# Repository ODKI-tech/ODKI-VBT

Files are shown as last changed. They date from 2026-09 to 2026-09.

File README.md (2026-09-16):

# ODKI VBT

**[odki.tech](https://odki.tech)** — project site, pre-orders, and the companion app.

ODKI VBT is a source-available **Velocity-Based Training (VBT)** sensor — a small wireless device that clips onto a barbell (or is otherwise attached to the load being lifted) and measures bar velocity, displacement, and rep count in real time, streaming the results to a companion app over Bluetooth Low Energy. Build your own from the files here for personal or research use, or buy a ready-made, ODKI-branded unit at [odki.tech](https://odki.tech) — see the license note below for exactly what "source-available" means here.

Velocity-based training uses how *fast* a lift moves — not just the weight on the bar — to gauge effort, fatigue, and training intensity in real time, which is the whole reason this project exists: an accessible, understandable, hackable device to do that.

Both the hardware and the firmware are source-available: anyone can read exactly how it works, build one for themselves, modify it, and share their own non-commercial improvements. Selling an assembled unit — under the ODKI name or otherwise, built from these files or a modified version of them — is reserved to ODKI; that's the one thing this isn't open to. See [LICENSE-FIRMWARE](LICENSE-FIRMWARE) and [LICENSE-HARDWARE](LICENSE-HARDWARE) for the exact terms of each, and [CONTRIBUTING.md](CONTRIBUTING.md) for how contributing to the official repository works.

## How it works, briefly

The sensor fuses its onboard accelerometer and gyroscope into a stable orientation estimate, uses that to isolate real acceleration from gravity, integrates it into velocity along the vertical axis, and detects individual reps from that velocity signal — continuously correcting for drift using brief natural pauses in motion, without requiring the athlete to explicitly mark the start/end of each rep. Every rep's peak/mean velocity, acceleration, displacement, and a data-quality score are reported live. The full algorithm is documented in detail in [`Firmware/DOCUMENTATION.md`](Firmware/DOCUMENTATION.md).

## Repository layout

- **[Hardware/](Hardware/)** — bill of materials, CAD/mechanical design files, and assembly instructions for building a unit.
- **[Firmware/](Firmware/)** — the Arduino C++ firmware source (`VBT_Quaternions/`), [`DOCUMENTATION.md`](Firmware/DOCUMENTATION.md) (a chapter-by-chapter reference covering what every source file does and the rep-detection algorithm in detail), [`BLE_PROTOCOL.md`](Firmware/BLE_PROTOCOL.md) (the byte-exact Bluetooth protocol spec — everything a third-party app needs to talk to the sensor), and two Python tools: `tools/vbt_log_viewer.py`, for replaying and visualizing a raw debug-log capture from the device, and `tools/vbt_live_monitor.py`, a desktop GUI that shows that same data live over a USB-serial connection and can drive calibration/start/stop directly, no phone app needed.
- **[Apps/](Apps/)** — download links and usage instructions for the companion app (Android, iOS, Windows).
- **[LICENSE-FIRMWARE](LICENSE-FIRMWARE)** (GPL-3.0 + Commons Clause) / **[LICENSE-HARDWARE](LICENSE-HARDWARE)** (CC BY-NC-SA 4.0) — non-commercial use, modification, and redistribution allowed; selling a unit built from these files is reserved to ODKI. The BLE protocol specification itself ([`Firmware/BLE_PROTOCOL.md`](Firmware/BLE_PROTOCOL.md)) is separately released under CC0 (public domain), so third-party apps can be built against it without restriction.

## Getting started

1. **Build the hardware.** The [bill of materials](Hardware/BOM/), [CAD/mechanical design](Hardware/CAD/), and [step-by-step assembly instructions](Hardware/Instructions/) are all published — start there.
2. **Flash the firmware.** Open `Firmware/VBT_Quaternions/VBT_Quaternions.ino` in the Arduino IDE with the `Seeeduino:nrf52` board package installed (board: `xiaonRF52840Sense`) and the `Seeed Arduino LSM6DS3` library, then upload. See [`Firmware/DOCUMENTATION.md`](Firmware/DOCUMENTATION.md) for what each file does and how the algorithm works.
3. **Install the app.** See [Apps/](Apps/) for your platform — currently pending first public release.
4. **Calibrate and lift.** Power on, connect over Bluetooth, calibrate the sensor while it's still, then start tracking a set.

## Contributing

Both the hardware and firmware are meant to be read and modified. `Firmware/DOCUMENTATION.md` is written specifically to get a new contributor from "never seen this codebase" to "can confidently modify the rep-detection algorithm" — start there. See [`CONTRIBUTING.md`](CONTRIBUTING.md) for how to report a bug, propose a change, and the code style expected in a pull request.

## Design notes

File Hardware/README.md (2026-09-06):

# Hardware

This folder holds everything needed to build the ODKI VBT sensor's physical hardware. The current reference design is built around a **Seeed XIAO nRF52840 Sense** module (which already integrates the nRF52840 MCU, an LSM6DS3TR-C accelerometer/gyroscope, BLE radio, and USB-C/battery charging), plus a LiPo battery and a physical power switch — see `Firmware/DOCUMENTATION.md` for how the firmware expects that switch to be wired (`WAKE_PIN`, `Config.h`).

- **[BOM/](BOM/)** — bill of materials: every part needed to build one unit, with quantities and key specs (no sourcing links — where to buy each part is up to you, see the note in [BOM/README.md](BOM/README.md)).
- **[CAD/](CAD/)** — the two-body enclosure design (source + print-ready files) and, if a custom PCB is ever designed instead of using the XIAO module directly, its schematic/layout sources.
- **[Instructions/](Instructions/)** — step-by-step assembly instructions, from raw parts to a working, closed unit ready to flash.

See [LICENSE-HARDWARE](../LICENSE-HARDWARE) at the project root for the license status of everything in this folder.

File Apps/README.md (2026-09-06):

# Apps

The ODKI VBT companion app connects to the sensor over Bluetooth Low Energy to calibrate it, start/stop tracking, view live velocity/rep data, and install firmware updates over the air.

**License note:** unlike the firmware and hardware design files in this repository, the app itself is closed-source and is not covered by [`LICENSE-FIRMWARE`](../LICENSE-FIRMWARE) or [`LICENSE-HARDWARE`](../LICENSE-HARDWARE) — only builds/installers are distributed here, no app source. Some of its features (training-data management, AI-based analysis) are paid; this has no effect on using the sensor itself, which works over the fully open [BLE protocol](../Firmware/BLE_PROTOCOL.md) regardless of which app — this one or a third-party alternative — you use with it.

Download and setup instructions for each platform:

- **[Android/](Android/)** — published.
- **[iOS/](iOS/)** — not yet published.
- **[Windows/](Windows/)** — not yet published.

See each platform's README for current status and, once published, the download link.

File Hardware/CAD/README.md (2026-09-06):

# CAD

Mechanical design source files for the ODKI VBT enclosure.

## Design

Two printed bodies, bonded together permanently with cyanoacrylate (superglue) rather than screwed or snap-fit — there is no intended way to reopen a unit non-destructively once assembled (replacing the battery means breaking the bond and reprinting/regluing).

- **`case-top`** — the main shell, holding the Seeed XIAO nRF52840 Sense. An internal rail guides the board into position as it slides in, until its USB-C connector lines up with a cutout in one of the two short end walls. The **opposite short end** has its own dedicated recess for the power switch. The top face also has a small separate oval window positioned over the onboard RGB status LED, so its color is visible from outside with the case fully closed.
- **`case-bottom`** — the shallower base, holding the LiPo battery and the 3 neodymium magnets (see [`Hardware/BOM`](../BOM/)) in their own blind pockets in the floor of the same compartment, used for the barbell-mount attachment. The magnets go in before the battery is placed, since the battery sits on top of them once the body is populated. A small integrated post does double duty: it keeps the battery from shifting inside the compartment, and — once the two halves are joined — it backs up the XIAO board from behind, so it can't be pushed back out of `case-top`'s rail if the USB-C cable is inserted with some force.

Because the USB-C port stays reachable through `case-top`'s cutout even once the unit is glued shut, a finished unit can still be charged over USB normally, day to day, without ever opening the case — that's the cutout's main job. Re-flashing over USB is also possible through the same cutout, but is only ever a fallback: normal firmware updates go over BLE DFU instead (see `Firmware/DOCUMENTATION.md`).

| `case-bottom`, interior | `case-top`, exterior | `case-top`, interior |
|---|---|---|
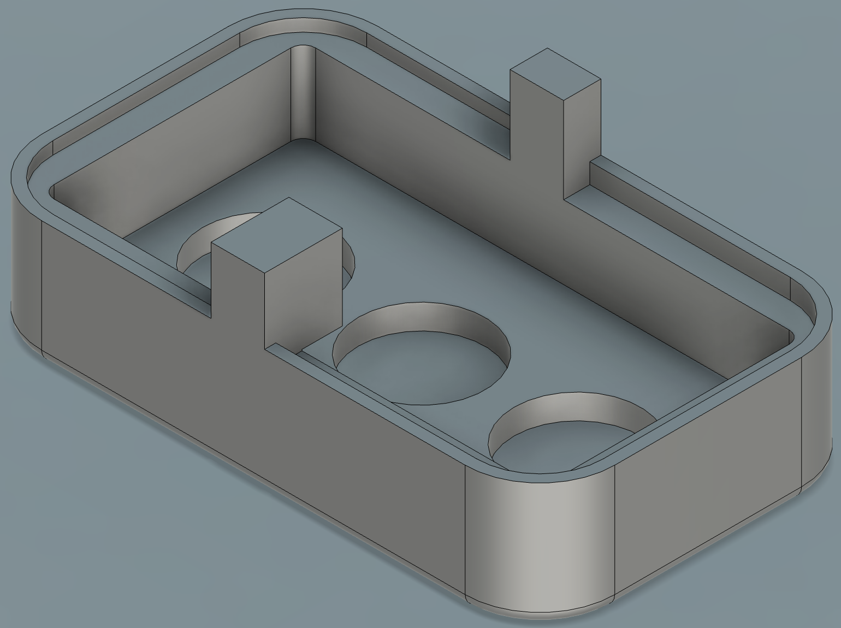
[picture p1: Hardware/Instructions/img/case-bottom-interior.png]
case-bottom interior, magnet pockets
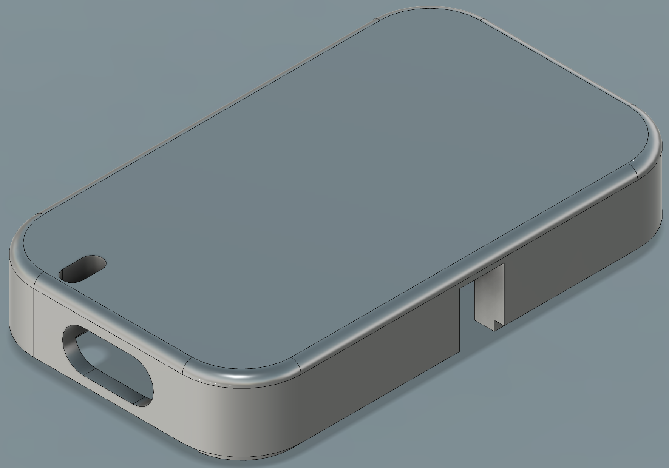
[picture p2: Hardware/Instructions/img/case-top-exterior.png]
case-top exterior, USB-C cutout and switch recess
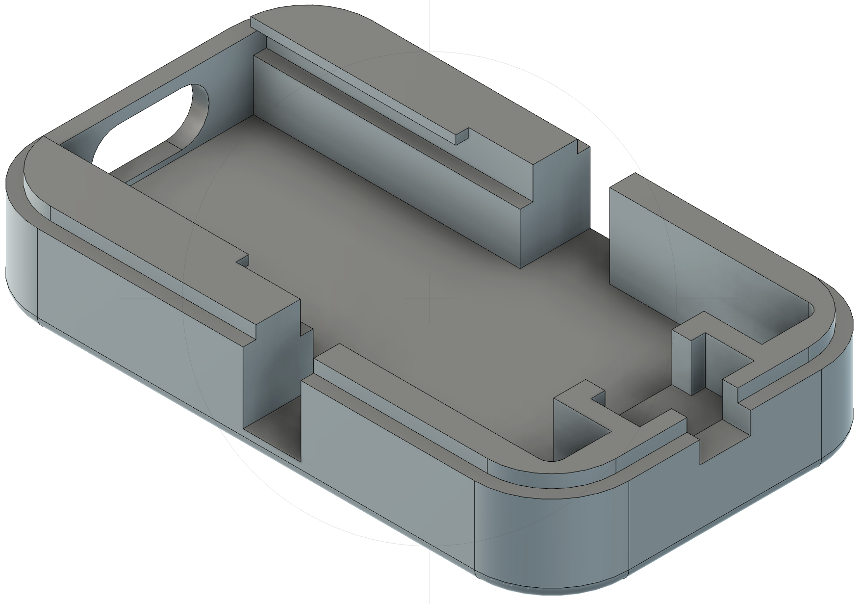
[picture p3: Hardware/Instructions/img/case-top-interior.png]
case-top interior, board rail and USB-C cutout
|  |  |  |

(Designed in Fusion 360. If a custom PCB is ever designed instead of using the XIAO module directly, its schematic/layout sources (e.g. KiCad) and exported gerbers would also go in this folder.)

## Print settings

Reference settings used for both bodies, printed in **PLA**:

| Setting | Value |
|---|---|
| Layer height | 0.2mm |
| Infill | 95% |
| Supports | Not needed for `case-top`; required for `case-bottom` |

## Files

| File | Format | Purpose |
|---|---|---|
| [`case-top.step`](case-top.step) | STEP | Editable source, opens in FreeCAD or any other CAD tool |
| [`case-top.stl`](case-top.stl) | STL | Ready-to-print mesh, for a slicer (Cura, PrusaSlicer, etc.) |
| [`case-bottom.step`](case-bottom.step) | STEP | Same as above, bottom body |
| [`case-bottom.stl`](case-bottom.stl) | STL | Same as above, bottom body |
| [`case-top.f3d`](case-top.f3d) / [`case-bottom.f3d`](case-bottom.f3d) | Fusion 360 archive | Optional — only useful to someone who also has Fusion and wants the full parametric history (sketches, feature timeline), which STEP does not preserve |

See [`Hardware/Instructions`](../Instructions/) for how these bodies fit together with the electronics into a finished unit.

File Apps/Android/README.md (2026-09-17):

# Android

**Status: published.** [Download the latest APK](https://github.com/ODKI-tech/ODKI-VBT/raw/main/Apps/Android/app-release/odki-vbt-latest.apk).

## Download & install

Distributed as a downloadable APK directly from [`app-release/`](app-release/) in this repository (sideload — no Google Play listing planned initially). Unlike the firmware (which self-checks for updates in-app), there's no auto-update mechanism for the app itself yet — check back here for a newer `.apk`.

1. Download [`odki-vbt-latest.apk`](https://github.com/ODKI-tech/ODKI-VBT/raw/main/Apps/Android/app-release/odki-vbt-latest.apk) — always the current release, regardless of version (see the note for maintainers below). Use the `github.com/.../raw/...` link specifically, not a plain `raw.githubusercontent.com` one — the APK is stored with Git LFS (see `.gitattributes`), and only the former correctly redirects to the actual binary; the latter serves the LFS pointer text instead (133 bytes, not the app).
2. Android will likely warn that installing from outside the Play Store is blocked — go to **Settings → Apps → Special access → Install unknown apps**, select the app you downloaded with (e.g. your browser or file manager), and allow it. The exact wording/path varies a bit by Android version and manufacturer.
3. Open the downloaded `.apk` and confirm the install.
4. To update later, just download and install the newer `.apk` the same way — it installs over the existing app as long as it's signed with the same key, no need to uninstall first.

**Note for maintainers, cutting a new release:** build the APK (`flutter build apk --release` in the app repo), overwrite `app-release/odki-vbt-latest.apk` with it, delete any other `.apk` left over in this folder, and bump `version` in the app repo's `pubspec.yaml` — same "keep only the latest, git history is the archive" convention as [`Firmware/firmware-release/`](../../Firmware/firmware-release/README.md). Keeping the filename itself stable (not versioned) is deliberate: it's what lets the link above, and everywhere else in this repo's docs, never need updating.

## Usage

1. Power on the sensor (see Hardware/Instructions).
2. Open the app, grant Bluetooth and location permissions when prompted (required by Android for BLE scanning).
3. Connect to the sensor from the device list.
4. Calibrate (hold the sensor/bar still and tap Calibrate).
5. Start a set to see live velocity and rep data; each completed rep appears automatically.
6. Firmware updates, when available, are offered in-app.

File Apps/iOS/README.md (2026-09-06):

# iOS

**Status: not yet published.** Link coming soon.

Planned distribution: TestFlight (Apple's beta-testing platform) for early testers, ahead of a possible App Store release. Once a TestFlight build is available, this page will list the invite link and installation steps (installing the free TestFlight app from the App Store, then redeeming the invite).

## Usage

1. Power on the sensor (see Hardware/Instructions).
2. Open the app, grant Bluetooth permission when prompted.
3. Connect to the sensor from the device list.
4. Calibrate (hold the sensor/bar still and tap Calibrate).
5. Start a set to see live velocity and rep data; each completed rep appears automatically.
6. Firmware updates, when available, are offered in-app.

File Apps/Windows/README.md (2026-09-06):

# Windows

**Status: not yet published.** Link coming soon.

Planned distribution: a downloadable installer/zip attached to this repository's GitHub Releases. Once published, this page will list the download link and setup steps. Note Windows PCs don't have built-in BLE peripheral tooling the way phones do — a Bluetooth LE-capable adapter (most modern laptops have one built in) is required.

## Usage

1. Power on the sensor (see Hardware/Instructions).
2. Open the app; pair/connect to the sensor from the device list.
3. Calibrate (hold the sensor/bar still and click Calibrate).
4. Start a set to see live velocity and rep data; each completed rep appears automatically.
5. Firmware updates, when available, are offered in-app.

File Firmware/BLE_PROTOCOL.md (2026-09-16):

# ODKI VBT — BLE Protocol Reference

**License note:** unlike the rest of this repository, *this document* is released under **CC0 1.0** (public domain dedication, see the [License](#license) section at the end) — deliberately, so any third-party app or integration can implement a client against it with zero legal uncertainty, commercial or not.

This is the byte-exact specification of the sensor's Bluetooth Low Energy interface: every characteristic UUID, every packet's layout down to the byte offset, and every scale factor needed to turn a raw value back into a physical one. It's written so a **third-party client** — a script, a different mobile app, a home-automation integration, anything — can talk to the device without needing to read the firmware source at all.

For *why* the protocol is shaped this way (why `Stream` is always raw, why `CorrectedCurve` exists and arrives late, why `RepSummary` can repeat), see the [BleServer chapter](DOCUMENTATION.md#bleserver) of the main firmware documentation — this document only covers *what's on the wire*, not the reasoning behind it. Reference implementation: `BleServer.h`/`.cpp` in this repository.

## Conventions

- **Byte order:** little-endian throughout — the nRF52840's native order, and standard for BLE.
- **No padding:** every packet struct in the firmware is declared `#pragma pack(push, 1)`, so byte offsets below are a plain cumulative sum of field sizes, with nothing inserted between fields.
- **Fixed-point physical values:** most quantities travel as a scaled integer, not a float: `physical_value = raw_value / scale`. This is called out per field below. A `scale` of `1` means the integer *is* the value directly (no conversion needed) — this is used for millisecond durations and millimetre-per-second velocities, so the wire value is already in a convenient integer unit.
- **Security:** every custom characteristic is open — `SECMODE_OPEN`, no pairing or bonding required for either read/notify or write access. Any BLE-capable device within range can connect, read live data, and issue `Command`/`Config` writes (including stopping tracking or changing algorithm parameters) without authentication. Keep this in mind if deploying in a setting where that matters.

## Advertising & connecting

| | |
|---|---|
| Device name | `VBT-Sensor` |
| Advertised service | the custom service UUID below |
| Role | Peripheral only (never Central) — exactly one simultaneous connection |
| Pairing | None required |

**MTU is mandatory to negotiate.** The default BLE MTU (23 bytes, 20 usable) is smaller than every custom packet except `Command`, `SystemStatus`, and `Battery`. Request the largest MTU the stack allows (the firmware itself requests up to 247 bytes on connect) before expecting `Stream`, `RepSummary`, `CorrectedCurve`, or `Config` to work — a client that skips this will simply never receive a successful notify for those characteristics.

## All UUIDs at a glance

| Name | UUID | Properties | Size |
|---|---|---|---|
| ODKI VBT Service | `6c7325bb-1784-4d77-8b99-89ce838ac2ab` | — | — |
| Stream | `6c7325bb-1784-4d77-8b99-89ce838ac2ac` | Notify | 37 B |
| RepSummary | `6c7325bb-1784-4d77-8b99-89ce838ac2ad` | Notify | 17 B |
| CorrectedCurve | `6c7325bb-1784-4d77-8b99-89ce838ac2ae` | Notify | 53 B |
| SystemStatus | `6c7325bb-1784-4d77-8b99-89ce838ac2af` | Read, Notify | 2 B |
| Command | `6c7325bb-1784-4d77-8b99-89ce838ac2b0` | Write | 1 B |
| Config | `6c7325bb-1784-4d77-8b99-89ce838ac2b2` | Read, Write | 38 B |
| Battery Service | `0x180F` (standard) | — | — |
| Battery Level | `0x2A19` (standard) | Read, Notify | 1 B |
| Device Information Service | `0x180A` (standard) | — | — |
| Firmware Revision String | `0x2A26` (standard) | Read | variable (UTF-8) |
| Buttonless DFU Service | `00001530-1212-efde-1523-785feabcd123` | — | — |
| DFU Control | `00001531-1212-efde-1523-785feabcd123` | Write, Notify | 1 B (command) |

(The custom UUIDs all share the base `6c7325bb-1784-4d77-8b99-89ce838ac2ab`, incrementing only the last byte — `0xb1` is intentionally absent from the sequence, freed when the original custom Battery and Firmware-Version characteristics were replaced by the two standard SIG services above.)

---

## Stream — `…c2ac`, Notify, 37 bytes

Live telemetry, sent only while tracking is active, decimated to 20Hz (`Config::STREAM_DECIMATION_FACTOR`). Automatically disabled while a raw serial debug capture is running.

| Offset | Size | Field | Type | Scale | Unit |
|---|---|---|---|---|---|
| 0 | 4 | `timestampMs` | uint32 | 1 | ms |
| 4 | 2 | `linAccX` | int16 | ÷100 | m/s² (sensor frame) |
| 6 | 2 | `linAccY` | int16 | ÷100 | m/s² |
| 8 | 2 | `linAccZ` | int16 | ÷100 | m/s² |
| 10 | 2 | `worldAccX` | int16 | ÷100 | m/s² (world frame) |
| 12 | 2 | `worldAccY` | int16 | ÷100 | m/s² |
| 14 | 2 | `worldAccZ` | int16 | ÷100 | m/s² |
| 16 | 2 | `worldVelX` | int16 | ÷1000 | m/s (debug/streaming only) |
| 18 | 2 | `worldVelY` | int16 | ÷1000 | m/s |
| 20 | 2 | `refVelZ` | int16 | ÷1000 | m/s — **raw**, live-re-anchored vertical velocity; never the retroactively-corrected value (see `CorrectedCurve` below) |
| 22 | 2 | `worldPosX` | int16 | ÷1000 | m |
| 24 | 2 | `worldPosY` | int16 | ÷1000 | m |
| 26 | 2 | `worldPosZ` | int16 | ÷1000 | m |
| 28 | 2 | `quatW` | int16 | ÷10000 | dimensionless, [-1, 1] |
| 30 | 2 | `quatX` | int16 | ÷10000 | dimensionless, [-1, 1] |
| 32 | 2 | `quatY` | int16 | ÷10000 | dimensionless, [-1, 1] |
| 34 | 2 | `quatZ` | int16 | ÷10000 | dimensionless, [-1, 1] |
| 36 | 1 | `phaseState` | uint8 | direct | `0`=Idle, `1`=Eccentric, `2`=Concentric |

Python decode: `struct.unpack("<I16hB", data)` — field order matches the table above.

---

## RepSummary — `…c2ad`, Notify, 17 bytes

One packet per completed rep. **The same `repNumber` can arrive more than once** as `correctionStatus` improves — a client must overwrite its stored copy of that rep by `repNumber`, never append a duplicate.

| Offset | Size | Field | Type | Scale | Unit |
|---|---|---|---|---|---|
| 0 | 1 | `repNumber` | uint8 | direct | 1-based |
| 1 | 2 | `peakVelocity` | int16 | ÷1000 | m/s, concentric |
| 3 | 2 | `meanVelocity` | int16 | ÷1000 | m/s, concentric |
| 5 | 2 | `peakAcceleration` | int16 | ÷100 | m/s², concentric |
| 7 | 2 | `meanAcceleration` | int16 | ÷100 | m/s², concentric |
| 9 | 2 | `displacementM` | uint16 | ÷1000 | m, concentric-only, always ≥0 |
| 11 | 2 | `eccPeakVelocity` | int16 | ÷1000 | m/s, `0` if this rep had no eccentric phase |
| 13 | 2 | `eccMeanVelocity` | int16 | ÷1000 | m/s, `0` if this rep had no eccentric phase |
| 15 | 1 | `quality1` | uint8 | direct | 0–100, kinematic confidence score |
| 16 | 1 | `correctionStatus` | uint8 | direct | `0`=Provisional, `1`=RepCalibrated, `2`=Corrected |

Python decode: `struct.unpack("<B4hH2hBB", data)`.

**`correctionStatus` in detail:**

| Value | Name | Meaning |
|---|---|---|
| `0` | Provisional | Scored against an extrapolated drift-rate estimate; the bracket containing this rep hasn't closed yet. Treat the numbers as a best-effort live estimate, not final. |
| `1` | RepCalibrated | Scored against a rep-cycle-based calibration (no bracket needed) — used when no bracket has closed recently, typically during a continuous, gapless set. |
| `2` | Corrected | Scored against a bracket's *measured* drift. Final — this `repNumber` will not be re-reported again. |

---

## CorrectedCurve — `…c2ae`, Notify, 53 bytes

Retroactively drift-corrected velocity for a time range that was already streamed as raw via `Stream`. Sent in chunks when the bracket covering that range closes; a bracket can span thousands of samples, far more than fit in one BLE packet. A client should replace the portion of its live graph already drawn from `Stream` in `[startTimestampMs, startTimestampMs + sampleCount × sampleIntervalMs)` with these values.

| Offset | Size | Field | Type | Scale | Unit |
|---|---|---|---|---|---|
| 0 | 2 | `bracketId` | uint16 | direct | increments on every bracket close |
| 2 | 2 | `chunkIndex` | uint16 | direct | 0-based, within this bracket |
| 4 | 2 | `totalChunks` | uint16 | direct | how many chunks this bracket was split into |
| 6 | 1 | `sampleCount` | uint8 | direct | how many of the 20 slots below are valid |
| 7 | 4 | `startTimestampMs` | uint32 | direct | ms — timestamp of `correctedVelZ[0]`, same clock/scale as `Stream::timestampMs` |
| 11 | 2 | `sampleIntervalMs` | uint16 | direct | ms between consecutive samples (nominally 10ms at 100Hz) |
| 13 | 40 | `correctedVelZ[0..19]` | int16 × 20 | ÷1000 | m/s each |

Only the first `sampleCount` entries of `correctedVelZ` are meaningful — a bracket's final chunk is usually partial, and the remaining slots are zero-padding to be ignored.

Python decode: `struct.unpack("<HHHBIH20h", data)`.

To reconstruct which of the already-received `Stream` samples a chunk corrects, match on timestamp: sample `i` in the chunk corresponds to `t = startTimestampMs + i × sampleIntervalMs`.

---

## SystemStatus — `…c2af`, Read/Notify, 2 bytes

Pushed automatically on every new connection and on every state change; also independently readable at any time via a standard GATT Read.

| Offset | Size | Field | Type | Meaning |
|---|---|---|---|---|
| 0 | 1 | `calibrated` | uint8 | `0`/`1` |
| 1 | 1 | `trackingActive` | uint8 | `0`/`1` |

`Start` (see `Command` below) is rejected by the firmware while `calibrated = 0`; `Calibrate` is rejected while `trackingActive = 1`.

---

## Command — `…c2b0`, Write, 1 byte

A single control byte:

| Value | Command | Effect |
|---|---|---|
| `0x00` | STOP | Stops tracking (if active). No effect otherwise. |
| `0x01` | START | Starts tracking. Ignored if the device isn't calibrated yet. |
| `0x02` | CALIBRATE | Blocking ~2s orientation calibration — the device must be held still. Ignored while tracking is active (stop first). |

Any other value, or a write shorter than 1 byte, is silently ignored.

---

## Config — `…c2b2`, Read/Write, 38 bytes

Runtime-adjustable algorithm parameters, mirroring the firmware's `RuntimeConfig` struct field-for-field. **Not persisted to flash** — the firmware always boots from its compiled defaults, so a client that wants non-default settings must re-send this characteristic on every new connection. Reading it returns whatever configuration is currently active (defaults, until a client writes otherwise). A write is echoed back into the Read value immediately, before the firmware has necessarily applied it internally.

See [`Firmware/DOCUMENTATION.md`](DOCUMENTATION.md#runtimeconfig-field-reference) for what each field actually controls in the algorithm — this table is the wire layout only.

| Offset | Size | Field | Type | Scale | Unit |
|---|---|---|---|---|---|
| 0 | 1 | `repDirection` | uint8 | direct | `0`=Up, `1`=Down |
| 1 | 2 | `maxPlausibleVelocityMmps` | uint16 | direct | mm/s |
| 3 | 2 | `accZBiasIdleStillTimeMs` | uint16 | direct | ms |
| 5 | 2 | `gyroBiasIdleStillTimeMs` | uint16 | direct | ms |
| 7 | 2 | `accZBiasGyroMaxDegSx10` | uint16 | ÷10 | degrees/s |
| 9 | 2 | `accZBiasAccMagToleranceX1000` | uint16 | ÷1000 | m/s² |
| 11 | 2 | `flatGuardMaxVelocityMmps` | uint16 | direct | mm/s |
| 13 | 1 | `velocityOverrideFlatWindowSamples` | uint8 | direct | samples |
| 14 | 2 | `velocityFlatBandMmps` | uint16 | direct | mm/s |
| 16 | 1 | `maxVelocityFlatWindowSamples` | uint8 | direct | samples |
| 17 | 1 | `minVelocityFlatWindowSamples` | uint8 | direct | samples |
| 18 | 2 | `accelerationFlatBandX1000Mps2` | uint16 | ÷1000 | m/s² |
| 20 | 1 | `maxAccelerationFlatWindowSamples` | uint8 | direct | samples |
| 21 | 1 | `minAccelerationFlatWindowSamples` | uint8 | direct | samples |
| 22 | 2 | `windowSaturationPeakVelocityMmps` | uint16 | direct | mm/s |
| 24 | 2 | `phaseStartVelocityMmps` | uint16 | direct | mm/s |
| 26 | 2 | `minPhaseDurationMs` | uint16 | direct | ms |
| 28 | 2 | `maxPhaseDurationMs` | uint16 | direct | ms |
| 30 | 1 | `phaseLookbackSamples` | uint8 | direct | samples |
| 31 | 1 | `reversalConfirmSamples` | uint8 | direct | samples |
| 32 | 2 | `emaAlphaX1000` | uint16 | ÷1000 | dimensionless, [0, 1] |
| 34 | 2 | `minCrossingExcursionMmps` | **int16** | direct | mm/s, always ≤ 0 |
| 36 | 2 | `minCrossingDurationMs` | uint16 | direct | ms |

Every field is unsigned except `minCrossingExcursionMmps` at offset 34 — the one signed field in the packet.

Python decode: `struct.unpack("<BHHHHHHBHBBHBBHHHHBBHhH", data)` — 23 fields, matching the table row order exactly (`B`, `H`×6, `B`, `H`, `BB`, `H`, `BB`, `H`×4, `BB`, `H`, `h`, `H`).

A write shorter than 38 bytes is ignored entirely (the whole packet, not just the missing tail).

**v3.11.27:** `flatGuardOverrideStillTimeMs` (a uint16 duration, was offset 13) was removed and replaced by `velocityOverrideFlatWindowSamples` (a uint8 sample count) at the same offset — the packet shrank from 39 to 38 bytes. The old field gated a raw gyroscope/accelerometer quiet-time safety net that in practice almost never fired (it required a full, unbroken second with zero noise anywhere in it); the new field instead widens the SAME velocity/acceleration flatness tests the sensor already runs (to a fixed 30–60 sample window) once the corrected velocity estimate is outside `flatGuardMaxVelocityMps` — see [`Firmware/DOCUMENTATION.md`](DOCUMENTATION.md#the-flat-guards-two-tier-design) for the full reasoning. A client built against the pre-v3.11.27 39-byte layout will have its Config writes silently ignored by v3.11.27+ firmware — update the packet size and field before talking to updated firmware.

**v3.11.24:** `debugLogEnabled` (offset 39) was removed — the packet shrank from 40 to 39 bytes. Whether the sensor prints its raw serial log or streams over BLE is now decided automatically from whether a USB-serial connection is open (see [`Firmware/DOCUMENTATION.md`](DOCUMENTATION.md#lab-data-capture-serial-log)), not a field a client sends.

---

## Battery Service (standard, `0x180F`)

**Battery Level** (`0x2A19`, Read/Notify, 1 byte): `percent`, uint8, direct, 0–100. Updated by the firmware every `Config::BATTERY_CHECK_INTERVAL_MS` (30s) and once immediately on boot.

## Device Information Service (standard, `0x180A`)

**Firmware Revision String** (`0x2A26`, Read, variable-length UTF-8): the firmware version as `"MAJOR.MINOR.PATCH"` (e.g. `"3.11.7"`). Set once at boot, static for the whole connection — read it to check whether an OTA update is available before offering one to the user.

## Firmware update (DFU)

Updating the firmware is a two-stage handoff, and only the first stage is custom to this project:

1. **Enter bootloader mode.** Write `0x01` to the DFU Control characteristic (`00001531-1212-efde-1523-785feabcd123`, under the Buttonless DFU service `00001530-1212-efde-1523-785feabcd123`). The device disconnects and reboots into the factory Adafruit bootloader.
2. **Transfer the firmware.** The bootloader now exposes Nordic's standard **Secure DFU** service — a public, well-documented Nordic protocol, unrelated to anything custom in this repository. Use an existing DFU-capable client library rather than implementing this stage from scratch (the companion app uses `nordic_dfu` on Flutter; equivalents exist for most platforms — e.g. Nordic's own `nRF Connect Device Manager` / `iOS-DFU-Library` / `Android-DFU-Library`).

There is no `.h`/`.cpp` in this firmware implementing the second stage — it's entirely the stock bootloader's responsibility, which is also why a device stuck mid-update can generally be recovered by simply reflashing over USB rather than needing another BLE transfer.

## License

This document (`BLE_PROTOCOL.md` only — not the firmware source it describes, see [`LICENSE-FIRMWARE`](../LICENSE-FIRMWARE) for that) is released under **CC0 1.0 Universal**: to the extent possible under law, the author(s) have waived all copyright and related or neighboring rights to this document. You may copy, modify, distribute, and use it — including commercially, including without attribution — with no conditions at all.

Full legal text: <https://creativecommons.org/publicdomain/zero/1.0/legalcode>

This applies only to the protocol *specification* in this file — implementing a compatible client (an app, a script, an integration) based on it is unrestricted. It does not relicense the firmware itself, which remains under [`LICENSE-FIRMWARE`](../LICENSE-FIRMWARE).

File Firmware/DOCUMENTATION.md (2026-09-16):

# ODKI VBT Firmware Documentation

**License note:** this document is covered by the same license as the firmware it describes — see [`LICENSE-FIRMWARE`](../LICENSE-FIRMWARE) (GPL-3.0 + Commons Clause) in the repository root. (The BLE wire protocol has its own, more permissive license — see the [License section](BLE_PROTOCOL.md#license) of `BLE_PROTOCOL.md`.)

This document describes the firmware that runs on the ODKI VBT sensor: a Seeed XIAO nRF52840 Sense (an nRF52840 microcontroller with an onboard LSM6DS3TR-C accelerometer/gyroscope), programmed with the Arduino framework. It is organized as one chapter per source file, in roughly the order a newcomer should read them: the entry point first, then the core rep-detection algorithm, then BLE, then the supporting hardware modules.

## What the device does

The sensor clips onto a barbell or is held during a lift. Once calibrated (held still for the CALIBRATE command) and started (the START command), it:

1. Fuses its accelerometer and gyroscope into a stable 3D orientation estimate.
2. Uses that orientation to isolate real (muscular) acceleration from gravity, and expresses it along a fixed vertical axis in the world, regardless of how the sensor is oriented on the bar.
3. Integrates that acceleration into velocity, continuously correcting for drift using brief moments of genuine stillness between reps.
4. Detects individual reps from the resulting velocity signal — including recovering multiple reps from a continuous set where the athlete never fully pauses between them — and reports peak/mean velocity, acceleration, displacement, and a data-quality score for each one.
5. Streams live telemetry and per-rep results to a companion app over Bluetooth Low Energy, and can log raw per-sample data over USB serial for offline analysis.

## Module map

| File | Responsibility |
|---|---|
| `VBT_Quaternions.ino` | Top-level orchestration: wires the modules together in `setup()`/`loop()`. |
| `Config.h` | Shared build-time constants (pins, firmware version, timing). |
| `MotionTracker.h` / `.cpp` | The core algorithm: IMU fusion, velocity integration, rep detection. |
| `BleServer.h` / `.cpp` | The Bluetooth peripheral: custom streaming/control service, wire protocol. |
| `MadgwickAHRS.h` / `.cpp` | The orientation filter (accelerometer + gyroscope sensor fusion). |
| `PowerManager.h` / `.cpp` | Power switch handling, hardware watchdog, deep sleep. |
| `BatteryMonitor.h` / `.cpp` | LiPo voltage reading, charge percentage, self-calibration. |
| `StatusLED.h` / `.cpp` | The onboard RGB status LED. |

The diagram below shows how these fit together at runtime — `VBT_Quaternions.ino` orchestrates every module from `setup()`/`loop()`; the only module that talks to the outside world is `BleServer`, over the custom BLE service described in its chapter.

```mermaid
flowchart TB
    ORCH["VBT_Quaternions.ino<br/>setup() / loop() orchestration"]

    IMU[("LSM6DS3TR-C<br/>accelerometer + gyroscope")]
    MADG["MadgwickAHRS<br/>orientation filter"]
    MT["MotionTracker<br/>velocity integration,<br/>phase/bracket rep detection"]
    PM["PowerManager<br/>switch · watchdog · deep sleep"]
    BATT["BatteryMonitor<br/>voltage · auto-calibration"]
    LED["StatusLED"]
    BLE["BleServer<br/>BLE peripheral"]

    ORCH --> PM
    ORCH --> BATT
    ORCH --> MT
    ORCH --> LED
    ORCH --> BLE

    IMU --> MT
    MT <--> MADG

    MT -- "reps, corrected-curve chunks" --> BLE
    BATT -- "battery %" --> BLE
    PM -. "wake / sleep" .-> ORCH
    MT -. "calibrated / tracking state" .-> LED
    BLE -. "connected state" .-> LED

    BLE <==>|"Stream · RepSummary · CorrectedCurve<br/>SystemStatus · Command · Config<br/>Battery · buttonless DFU"| APP["Companion app<br/>Android / iOS / Windows"]
```

## Required libraries

- **Seeed Arduino LSM6DS3** (Seeed Studio) — IMU driver.
- **Bluefruit52Lib** — ships with the `Seeeduino:nrf52` Arduino board package; no separate install needed.
- **Adafruit TinyUSB** — USB CDC serial, used for the debug log.

Board package: `Seeeduino:nrf52`, board `xiaonRF52840Sense`.

## Tooling

`tools/vbt_log_viewer.py` is a Python companion script for the raw debug log described in the [Lab data capture](#lab-data-capture-serial-log) section below. It parses a capture (opening a serial connection to the sensor is now enough to produce one, see that section — v3.11.24), offline-reconstructs the drift-corrected curve with the exact same formula the firmware uses, prints a per-rep recap and an anomaly scan to the console, and plots raw vs. corrected velocity — either as a static overview (`python vbt_log_viewer.py session.log --save overview.png`) or as an animated real-time playback (`--live`). It's what produced both images in the MotionTracker chapter, from a real capture. Requires `numpy`, `pandas`, and `matplotlib` (`pip install numpy pandas matplotlib`).

`tools/vbt_live_monitor.py` (v3.11.25+) is a Tkinter GUI that opens the same USB-serial connection *live* instead of replaying a saved file: a rolling chart of raw and/or corrected velocity (togglable — raw / live / both) with the flat-guard's ±0.20 m/s ceiling and every confirmed-stillness/discarded-phase event marked, acceleration, a big current-phase/rep readout, a table of completed reps as they're scored, and a console for every other line the firmware prints (battery, BLE messages, calibration warnings). Its Calibrate/Start/Stop buttons send the plain-text `CALIBRATE`/`START`/`STOP` serial commands added in v3.11.21/v3.11.22 (`pollSerialCommands()` in the .ino) — the whole tracking lifecycle can now be driven without the phone app, and since v3.11.24 the sensor starts printing its raw log the moment this tool's serial connection opens (see [Lab data capture](#lab-data-capture-serial-log)) — no app step needed for that either; only the runtime Config (rep direction, phase thresholds, …) is still BLE-only. A Delay dropdown next to START (off, or 5–30s in steps of 5) is a self-timer local to the tool — it holds off sending `START` for that long, counting down in the big phase readout, so whoever's about to lift has time to get under the bar; the firmware itself is unaware of it and still receives a plain immediate `START` once the count reaches zero. It can optionally record every raw line to a `.log` file as it streams, which `vbt_log_viewer.py` can then replay offline. Requires `pyserial`, `numpy`, and `matplotlib` (`pip install pyserial numpy matplotlib`) plus Tkinter (bundled with the python.org installers; `sudo apt install python3-tk` on Debian/Ubuntu).

**v3.11.25 — redraw throttling:** user-reported high CPU/heat during use, and stalls when the window was resized to fullscreen or a dropdown was opened. The matplotlib redraw — not the 100Hz serial read, which stays cheap — is the actual cost, and it used to run on a fixed ~20fps timer regardless of whether anything had changed, including while idle, disconnected, or paused. It's now skipped entirely when nothing new arrived since the last frame, and throttled to ~8fps while actively streaming (see the module docstring for the full explanation, including why this was also the root cause of the fullscreen/dropdown stalls — Tkinter is single-threaded, so a background timer doing expensive rendering was competing with the OS's own resize/popup handling on the same thread). `SampleBuffer` is also now capped to the largest selectable window (60s, was 10 minutes of history nothing ever displays), so the per-frame cost stays constant instead of slowly growing over a long session.

---

## VBT_Quaternions.ino

The top-level sketch. Deliberately thin — its only job is wiring the other modules together in `setup()`/`loop()`; all the actual logic lives in the modules it calls into (`MotionTracker`, `BleServer`, `PowerManager`, `BatteryMonitor`, `StatusLED`).

**`setup()`**: brings up power management and the status LED first (so a very early failure is still visible), then the battery monitor, then logs the reset reason (useful for distinguishing a normal power-on from a watchdog-triggered recovery — see the PowerManager chapter), then starts BLE — which must happen before any possible call to deep sleep, since sleep entry depends on the BLE SoftDevice already being active — and finally the IMU. If the power switch isn't closed at boot, or the IMU fails to initialize, the device goes back to sleep or halts (blinking its status LED) rather than continuing in a half-working state.

**`loop()`** runs, in order:
1. Feeds the watchdog first, so anything that hangs further down in this same iteration (including a hang inside `goToSleep()` itself) still gets caught.
2. Checks the power switch; goes back to sleep if it's open.
3. Recomputes the status LED from current state.
4. Drains any pending BLE command (CALIBRATE / START / STOP) and any pending Config write, applying each to `MotionTracker`.
4b. Drains any pending **serial** command (v3.11.21/v3.11.22, `pollSerialCommands()`) — `START`/`STOP`/`CALIBRATE`, as plain newline-terminated text (case-insensitive), mirroring the same guarded calls used for the BLE versions of each. Added for `tools/vbt_live_monitor.py`, a desktop tool with no BLE access. `CALIBRATE` is exactly as blocking and pose-sensitive here as over BLE (~2s, device held still — see `MotionTracker::calibrateOrientation()`) — this only adds a second way to trigger it, not a gentler one. Runtime Config stays BLE-only deliberately — it already has a typed BLE packet (see `BleServer.h`) a text command would just duplicate. Reads `Serial.available()` one character at a time into a small fixed buffer rather than `Serial.readStringUntil()` — the latter blocks up to `Serial`'s timeout (1s by default) when a line arrives incomplete, which would stall the 100Hz sampling loop; this way an incomplete or malformed line just waits harmlessly in the buffer for its next character, or resets if the buffer's 16-byte cap is exceeded.
5. Reports battery status, gated to once every `Config::BATTERY_CHECK_INTERVAL_MS`, independent of tracking state.
6. Calls `MotionTracker::update()`, which self-limits to 100Hz internally and returns `true` only when it actually computed a new sample — everything below is gated on that, since `loop()` itself runs much faster than 100Hz and would otherwise repeat stale work between real updates.
7. If a new sample was computed and tracking is active: attempts to deliver one completed rep, then one queued corrected-curve chunk (see the MotionTracker and BleServer chapters for why both of these are peek/pop patterns rather than a single blocking send), then, decimated to 20Hz and only when the raw debug log isn't active, sends the live Stream packet.
## Config

The smallest file in the firmware: four build-time constants that don't belong to any single module.

- `WAKE_PIN` (`D6`) — the power switch input pin, shared between `PowerManager` (reading it) and the pin-mode setup that happens there.
- `FirmwareVersion::{MAJOR, MINOR, PATCH}` — the firmware version, exposed over BLE via the standard Device Information Service (see the BleServer chapter) so the companion app can compare it against the latest available release and offer an OTA update without any manual step from the user. Increment on every release.
- `Config::BATTERY_CHECK_INTERVAL_MS` (30000) — how often the main loop re-reads and reports battery status, independent of whether tracking is active.
- `Config::STREAM_DECIMATION_FACTOR` (5) — the internal IMU/motion-tracking loop runs at 100Hz, but the BLE Stream characteristic sends only 1 sample in every N, to avoid saturating the connection: 100Hz / 5 = 20Hz over the air.

## MotionTracker

This is the core of the firmware: it reads the IMU, fuses it into a stable orientation, integrates that into a vertical velocity, and turns that velocity signal into discrete, measured reps. Everything else in the firmware (BLE streaming, the live LED, the debug log) is a consumer of what this module produces.

The rep-detection engine was rebuilt from scratch in v3.11.0 (replacing an earlier zero-velocity-update/ZUPT design used through v3.10.x) after real-hardware testing kept surfacing the same structural problem: any scheme that periodically forces the integrated velocity back to exactly zero has to decide, sample by sample, whether "the sensor looks quiet" really means "the sensor is at rest" — and during a slow rep, or right at a rep's own peak (where acceleration crosses zero by definition), those two things can look identical for a moment. The current design sidesteps the problem instead of patching around it: **the integrated velocity is never reset**. It is always the true, raw integral of acceleration, so it can never "jump". Genuine stillness is still detected — it's what makes the whole system work — but instead of being used to *reset* the signal, it's used to *measure how far the signal has drifted* since the last time the sensor was still, and that measured drift is then subtracted back out **retroactively**, across the whole interval it accumulated over. Two independent scan tools exist to see this in practice — a live per-sample debug log (see [Lab data capture](#lab-data-capture-serial-log) below) and the `tools/vbt_log_viewer.py` companion script, which replays a captured log exactly as the algorithm saw it and produces the plots referenced throughout this chapter.

### Pipeline overview

Every sample (100Hz, gated inside `update()`) goes through:

1. **`updateOrientationAndAcceleration()`** — reads the IMU, runs the Madgwick filter to get an orientation quaternion, and uses that orientation to split the raw accelerometer reading into gravity and *linear* acceleration, expressed in a fixed world frame instead of the sensor's own (rotating) frame. Also drives the two continuous bias estimates (below).
2. **`stepPhaseEngine()`** (called from `integrateMotion()`) — integrates world-frame vertical acceleration into a velocity that is *never* reset, decides moment to moment whether a rep **phase** (a concentric or eccentric half-rep) should open or close, and separately decides whether the sensor is genuinely still right now. Every sample is also appended to a rolling **bracket** buffer.
3. **Bracket close** — whenever a genuine stillness event begins, the bracket that has been accumulating since the *previous* stillness event closes: the drift it picked up is measured directly (raw velocity vs. the last known-good reference) and distributed back across every sample in that bracket, retroactively. Any phase that closed while inside that bracket gets rescored on the now-corrected curve and re-reported.
4. Two small FIFO queues — completed reps and corrected-curve chunks — hold results until `VBT_Quaternions.ino` successfully delivers each one over BLE, one at a time.

The image below shows the whole mechanism on a real capture (23 reps, 43.7s, `tools/vbt_log_viewer.py test_log.txt`): the grey line is the raw, never-reset integral; the blue line is what the corrected curve looks like once every bracket in the session has closed. Notice the raw curve visibly creeping upward as a baseline offset over the course of the set — pure integration drift — while the corrected curve keeps returning cleanly to zero between reps.

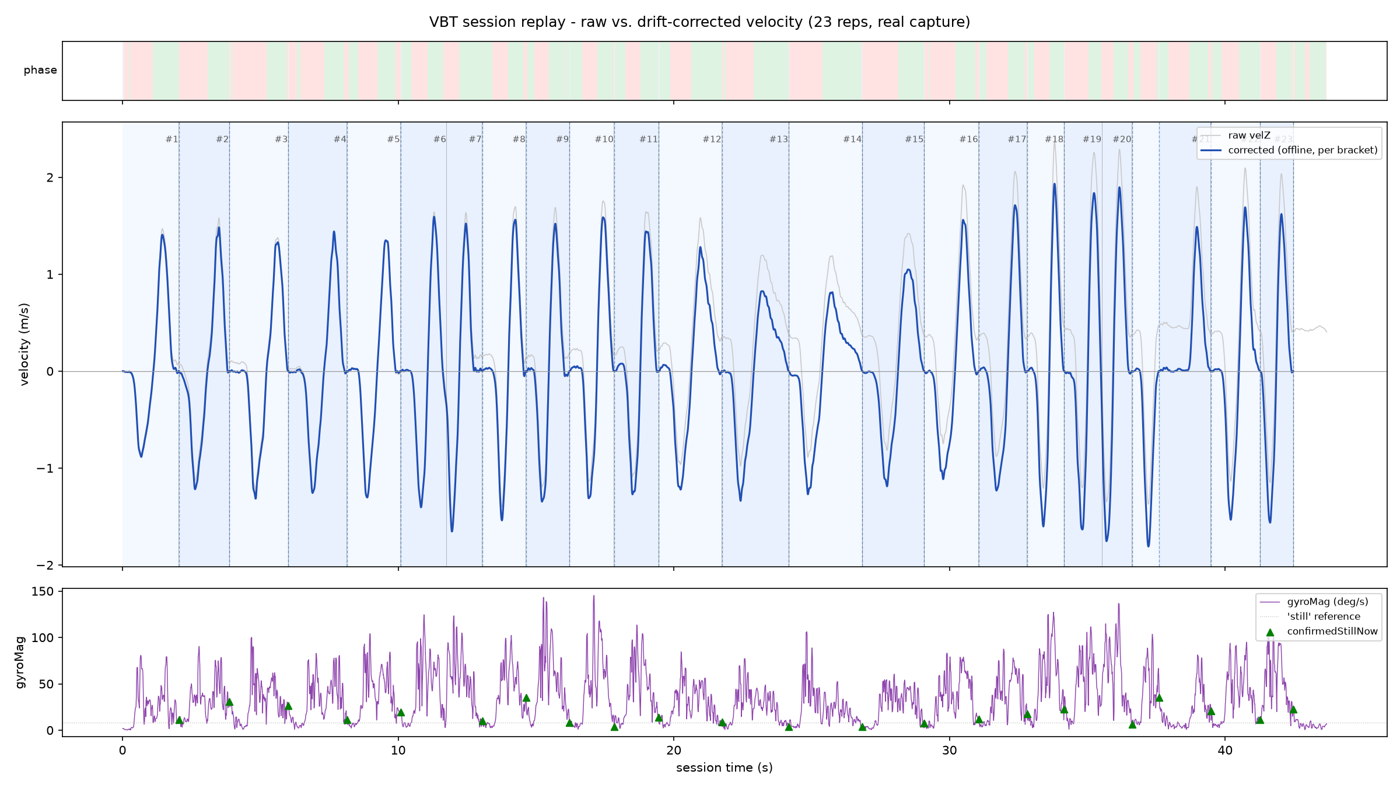
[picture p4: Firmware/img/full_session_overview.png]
Full session: raw vs. drift-corrected velocity, 23 reps


### Sensor reading and orientation

The LSM6DS3 IMU samples internally at 416Hz, but processing runs at 100Hz. `FastSampleAccumulator::poll()` is called on every `loop()` iteration (much faster than 100Hz) and accumulates every genuinely new IMU sample by checking the status register directly; `harvest()` averages whatever arrived since the last processed sample. This means no IMU sample is silently dropped between two 10ms ticks — they're all averaged in, which is a basic anti-aliasing measure.

Both the raw accelerometer and gyroscope readings pass through a 5-sample median filter (`MedianFilter3`) before anything else touches them. A median filter (not a moving average) rejects an *isolated* outlier sample (e.g. the mechanical shock of a barbell touching the floor, or an occasional I2C/BLE-radio glitch) almost entirely, while barely affecting a real, sustained acceleration that spans several consecutive samples the way muscular effort does. It costs (N-1)/2 samples of latency (20ms at N=5).

The gyroscope, converted to rad/s after bias subtraction, and the filtered accelerometer feed a [Madgwick AHRS filter](#madgwickahrs) with an *adaptive* gain: the filter's `beta` (how strongly the accelerometer correction pulls the orientation estimate) is scaled down whenever the measured acceleration magnitude departs from gravity — i.e. during real motion, when the accelerometer is no longer a trustworthy "down" reference. A floor (`TRUST_FLOOR`) keeps a minimum correction active even during a long explosive movement, so orientation never relies purely on the gyroscope (which would drift unboundedly) for an extended stretch.

The resulting quaternion is used to:
- Subtract gravity from the raw accelerometer reading, in the sensor's own frame, yielding `linAcc*` — genuine linear (muscular) acceleration.
- Rotate `linAcc*` into the world frame (`worldAcc*`), where "vertical" is a fixed axis regardless of how the sensor is oriented on the barbell/limb.

### Continuous bias estimation

Two slow-moving biases are estimated continuously, both gated on the *same* "is the sensor truly still right now" condition (low gyroscope magnitude AND accelerometer magnitude **flat** over a short sliding window), sustained for `RuntimeConfig::accZBiasIdleStillTimeS`:

- **`accZBias`** (now `accBiasVec`, see the v3.11.13 note below) — even a well-calibrated orientation leaves a small residual offset on the world-frame vertical acceleration (alignment error, slow orientation drift during motion). Without correcting for it, integrated velocity would never return to exactly zero at rest. Estimated with a ~2s time constant, frozen during real motion. Tuned via `RuntimeConfig::accZBiasGyroMaxDegS`/`accZBiasAccMagToleranceMps2` (the "quiet enough to trust" thresholds).
- **Gyroscope bias** — the zero-rate offset seeded once during `calibrateOrientation()` can shift during a session (typically thermal drift as the chip warms up). Left uncorrected, a stale bias slowly rotates the estimated "up" direction, which is the most likely cause of a slow `accZBias` drift on long sessions. Uses a much slower ~8s time constant (`RuntimeConfig::gyroBiasIdleStillTimeS` gates when it engages), since the goal here is tracking thermal drift, not reacting quickly.

This is the same raw, IMU-only stillness signal (gyroscope magnitude + the accelerometer-magnitude flatness window, nothing derived from the velocity estimate itself) that also backs the flat-guard override described below — it is deliberately kept independent of any velocity-based judgment of "quiet."

**v3.11.11 fix — why "flat" instead of "close to `G`":** earlier versions gated the accelerometer half of this condition on `|accMag − G| < accZBiasAccMagToleranceMps2` — an *absolute* comparison against gravity. That's only reliable if the accelerometer's magnitude scale (`accelScaleG`, fit once, isotropically, in `calibrateOrientation()`) corrects the sensor perfectly at *every* orientation, which a single scalar generally can't do on a real MEMS part with any per-axis sensitivity mismatch. At a resting orientation different from the one used at calibration time, `accMag` could read stably outside tolerance while the device was genuinely still (gyroscope confirmed near-zero), permanently blocking both bias updates and leaving `accZBias` frozen at a value inherited from a previous session/orientation — diagnosed on a real capture that was pure rotation with no translation at all, where this froze `accZBias` for 8.8s and drove `velZ` to the safety clamp. The gate now checks that `accMag` is *flat* (low excursion) over a short window instead, which is orientation-independent by construction and needs no protocol change (it reuses `accZBiasAccMagToleranceMps2` as the excursion half-band rather than an absolute-difference tolerance).

**v3.11.13 fix — a vector, not a scalar:** even after the fix above, real hardware logs showed the residual itself isn't constant — it depends on the device's *current* orientation (0.33 m/s² near the calibration orientation, 0.15 m/s² at a moderate tilt, on the same capture), because a single isotropic accelerometer scale factor can't fully correct a real MEMS part's per-axis sensitivity mismatch at every attitude. `accZBias` was replaced with `accBiasVec`, a fixed vector in the sensor's own body frame, projected onto the *current* gravity direction (`gravBodyX/Y/Z`, already computed every sample from the orientation quaternion) to get the correction to apply right now — it adapts as the device's orientation changes, including during motion, not just at the one orientation it happened to be resting at when the estimate last updated. The update rule is the same single-observation LMS step as before, just applied to a 3-vector instead of a scalar (it reduces to the exact old scalar EMA in the special case where gravity's direction in the body frame never changes). This corrects the *symptom* in the velocity domain using the existing single-position `calibrateOrientation()` — it does not fix the anisotropy in the Madgwick orientation estimate itself, which would need a proper multi-position, per-axis accelerometer calibration.

**v3.11.14 fix — from a cumulative counter to a sliding window:** the "quiet enough to trust" signal itself used to be a single cumulative duration counter (`accZBiasStillDuration`) that reset **completely** to zero on the very first violation — one isolated noisy sample (a rack or floor vibration, a hand not perfectly still) threw away all the time already accumulated, forcing a full wait from scratch. This made both bias updates *and* the flat-guard override (below) far slower and more unpredictable than they needed to be in a normal, slightly noisy environment. It's now the same sliding-window logic already used elsewhere in this engine (`excursionFlat`/`absoluteFlat`, generalized to take the ring's capacity as an explicit parameter): raw gyroscope magnitude and accelerometer magnitude are kept on two rolling history buffers, and each of the timers that depend on this signal (`accZBiasIdleStillTimeS`, `gyroBiasIdleStillTimeS`, and — until v3.11.27 replaced it, see [below](#the-flat-guards-two-tier-design) — `flatGuardOverrideStillTimeS`) just checks a different window length over the *same* two buffers. An isolated bad sample now costs at most one window's worth of delay — it ages out on its own — never a full reset.

### Velocity integration — never reset

`velZ` is the authoritative signed vertical velocity: positive is up, negative is down, always, independent of which direction is configured as the "concentric" one (`RuntimeConfig::repDirection`, applied once via a `+1/-1` sign multiplier immediately after integration — every other part of the engine works on the already-oriented value). It is integrated trapezoidally from `worldAccZ` every sample and — this is the structural change from the old design — **never touched again**: not zeroed, and (since v3.11.19) not clamped either. Whatever bias remains after the continuous `accZBias` correction above accumulates in `velZ` indefinitely; correcting for that accumulated drift is the entire job of the bracket mechanism below, not of the integration step itself. `±RuntimeConfig::maxPlausibleVelocityMps` is still a hard sanity ceiling, but it applies to `velZLive` (the corrected estimate computed a few lines later, see [Rep phases](#rep-phases-opening-and-closing) below) — clamping `velZ` itself, as earlier versions did, meant a long or touch-and-go set that legitimately drifted past 4&nbsp;m/s (drift, never real bar speed) fed a *clipped* raw sample into the bracket's drift measurement and the corrected-curve math, silently corrupting both for as long as the clamp was active.

### Mechanical shocks (open issue)

A mechanical shock — the bar briefly touching the floor between the eccentric and the concentric, most common in a touch-and-go deadlift or squat — produces a near-**instantaneous** jump in `worldAccZ` that a genuine muscular push never does, and that jump integrates directly into `velZ` as a real, if brief, error. The bracket mechanism (below) doesn't fully absorb it: it corrects drift **linearly over time** across a whole interval, the *opposite* shape from a shock's error (a step concentrated in a handful of samples), so the peak/mean of whichever phase the shock falls inside can stay measurably off even after correction — confirmed on a real capture (8 squats with progressively stronger intentional shocks), where the sharpest one reported a final, fully-corrected peak velocity off by ~0.15–0.22 m/s.

A jerk-based filter (holding the previous sample's value whenever the change from one sample to the next was implausibly large) was tried and briefly shipped, then removed: it fixed the isolated-shock case above, but made drift measurably *worse* on a different real capture of continuous, rapidly-alternating shaking — holding through one side of a pair of closely-spaced opposing spikes can swallow the natural cancellation that plain, unfiltered integration would otherwise provide on its own, since the two spikes largely cancel each other out if left alone. A short moving-average low-pass on `velZ` was evaluated as a safer alternative — it never made drift worse in that same capture — but was too weak at a window short enough to avoid also flattening genuine fast-rep peaks once widened enough to meaningfully help the isolated-shock case.

No mitigation is currently active. This remains an open problem — see the project's issue tracker / contribution history for the reasoning above if picking this up again.

### Rep phases: opening and closing

A **phase** is one concentric or eccentric half-rep — the same concept the very first (pre-ZUPT) version of this firmware used, now evaluated on a corrected estimate rather than the raw one (see the next section for why that distinction matters). A phase opens when the current best-estimate velocity crosses `RuntimeConfig::phaseStartVelocityMps` in either direction, and closes for one of three reasons:

- **Flat** — the flat-guard (below) confirms the sensor has gone still. This is what ends a normal rep.
- **Reversal** — the velocity has been moving the opposite way for `RuntimeConfig::reversalConfirmSamples` consecutive samples: the athlete changed direction without a real pause (e.g. bottom of a squat with no dead stop).
- **Timeout** — the phase has been open longer than `RuntimeConfig::maxPhaseDurationS`, a safety net against a phase that never resolves.

Two reps form a pair: an eccentric phase followed by the concentric phase that completes it. `RepResult` is only reported once the concentric side is known (see [Correction status](#correction-status-and-re-reporting) below); the eccentric side, if present, is folded in alongside it.

**v3.11.18 fix — rep numbering assumed phases always alternate direction:** the rep counter (`currentRepNumberEngine`) used to advance only when a phase closed in the *opposite* direction from the last one that closed (tracked via a `lastPhaseType` variable) — an assumption that a real capture broke: one concentric phase closed and was immediately followed by another concentric phase in the same direction, with no real reversal in between (visible in the raw log as one smooth, uninterrupted ascent silently cut into two "reps" by the engine — almost certainly a spurious flat/reversal false-trigger, not a genuine direction change). Once that happens, the alternation assumption never recovers: every eccentric phase reported afterward gets attributed to the *previous* rep's slot instead of its own, permanently, for the rest of the session — confirmed in the diagnosed capture from that point through its end. Fixed by making the counter advance unconditionally whenever a **concentric** phase closes, regardless of what closed before it — a rep is complete once its concentric phase closes, by definition, independent of anything else. `lastPhaseType` is gone entirely. A future spurious same-direction split now produces one orphaned rep (recognizable by a zero eccentric side) instead of corrupting every rep reported afterward.

### Flat-guard: deciding "the sensor is still"

This is the single most important judgment call in the whole engine, because it drives *everything* downstream: phase closing, bracket closing, and the continuous bias re-anchoring in the next section. It combines two independent tests, both evaluated over a **dynamically sized recent window** (`computeDynamicWindowSamples()`: the window shrinks from `maxVelocityFlatWindowSamples`/`maxAccelerationFlatWindowSamples` down to the `min…` values as the phase's own peak velocity rises toward `windowSaturationPeakVelocityMps` — a fast rep needs to confirm stillness quickly, a slow one can afford to wait longer to be sure):

- **Velocity excursion flat** — the recent window of velocity stays within `RuntimeConfig::velocityFlatBandMps` of itself.
- **Acceleration flat** — every sample in the recent acceleration window is within `RuntimeConfig::accelerationFlatBandMps2` of zero.

While a phase is open, which window these two tests read is itself two-tiered (v3.11.27, see [below](#the-flat-guards-two-tier-design)): under the absolute ceiling `RuntimeConfig::flatGuardMaxVelocityMps`, both use the dynamic window described above; once the corrected velocity exceeds it, both switch to a fixed, wider window (`RuntimeConfig::velocityOverrideFlatWindowSamples`) instead.

Both conditions are evaluated on a **corrected, live estimate of velocity** (`velZ` minus the current best prediction of how much it has drifted — see `livePredictedOffset()`), *not* on the raw integral. This is deliberate, and it is the fix that made the whole retroactive-correction design actually work in practice: on a long or heavy set, the raw integral can drift past the flat-guard's velocity ceiling entirely, and if the ceiling were evaluated on the raw value, the flat-guard would simply never fire again for the rest of the session — no more brackets would close, and drift correction would silently stop (this failure mode was diagnosed on a real capture: one flat-guard close in 24 seconds). Evaluating against the corrected estimate instead means the ceiling check keeps working even while the raw integral drifts arbitrarily far, because it's the *drift-corrected* number being checked against it, not the raw one.

**v3.11.16 fix — the window-sizing peak had the same raw-vs-corrected problem:** `computeDynamicWindowSamples()` needs to know the phase's peak velocity to decide how far to shrink the window, and that peak was tracked from the raw `velZ` sample rather than the corrected estimate — the same class of bug fixed twice in v3.11.8 for the direction test elsewhere in the engine (raw `velZ` never resets, so once accumulated drift is large relative to a phase's real amplitude, its magnitude no longer reflects the actual motion). Concretely: after enough raw drift has built up over a long session, a genuinely *slow* rep could read an inflated peak from the drifted baseline alone, pick the short windows meant for a fast rep, and confirm "flat" with less real stillness than it should. Not traced to a specific hardware report — found by re-examining the v3.11.8 fix, whose own note had explicitly left this exact usage alone at the time ("no evidence it's broken"). Fixed by tracking the peak from the same corrected estimate already used for the direction test right next to it.

**v3.11.17 fix — idle reset the window to the SLOWEST setting, not the fastest:** the dynamic window above only makes sense while a phase is open, sized against *that* phase's own peak velocity. While idle (no phase open, between a close and the next open) there is no such context — yet `closePhaseFn()` reset `phaseVelWindowSamples`/`phaseAccWindowSamples` to the **max** window (`maxVelocityFlatWindowSamples`/`maxAccelerationFlatWindowSamples`, 300ms by default) on every close, including a close caused by flatness itself, i.e. right after the engine had just proven stillness with a much smaller window (down to 2 samples for a fast rep). Since the absolute-ceiling half of the flat-guard is bypassed while idle (see the bullet list above — "while a phase is open" only), the re-anchor that zeroes the live reading depended solely on the excursion test over this now-oversized window, which still contained the tail of the deceleration into that very stillness — so it kept failing, and the live reading stayed away from zero, for up to ~300ms after a real, complete stop. Worse: if raw drift crossed `phaseStartVelocityMps` during that gap (it defaults to the same 0.2 m/s as `flatGuardMaxVelocityMps`), a spurious phase could reopen and reset the window to max again, compounding the delay until the old raw-stillness override (1.0s, meant as a rare last resort - since replaced, see [below](#the-flat-guards-two-tier-design)) stepped in to unstick it — user-reported as the live velocity sticking around ~0.20 m/s for close to a second after every stop. Fixed by resetting to the **min** window instead (`minVelocityFlatWindowSamples`/`minAccelerationFlatWindowSamples`, mirrored in `resetTracking()` at session start): idle has no peak-velocity context to size against, and the goal there is only to reconfirm stillness as fast as possible. A genuine stop now re-anchors within about one sample interval (10ms) instead of up to ~300ms, and the old override is no longer needed for the normal case.

The picture below zooms into the first four brackets of a real capture and annotates each close: the raw curve (grey) keeps a small residual offset after every rep, and the moment the flat-guard confirms stillness (green triangle, `confirmedStillNow`), the bracket closes and the corrected curve (blue) snaps back down to that segment's true zero.

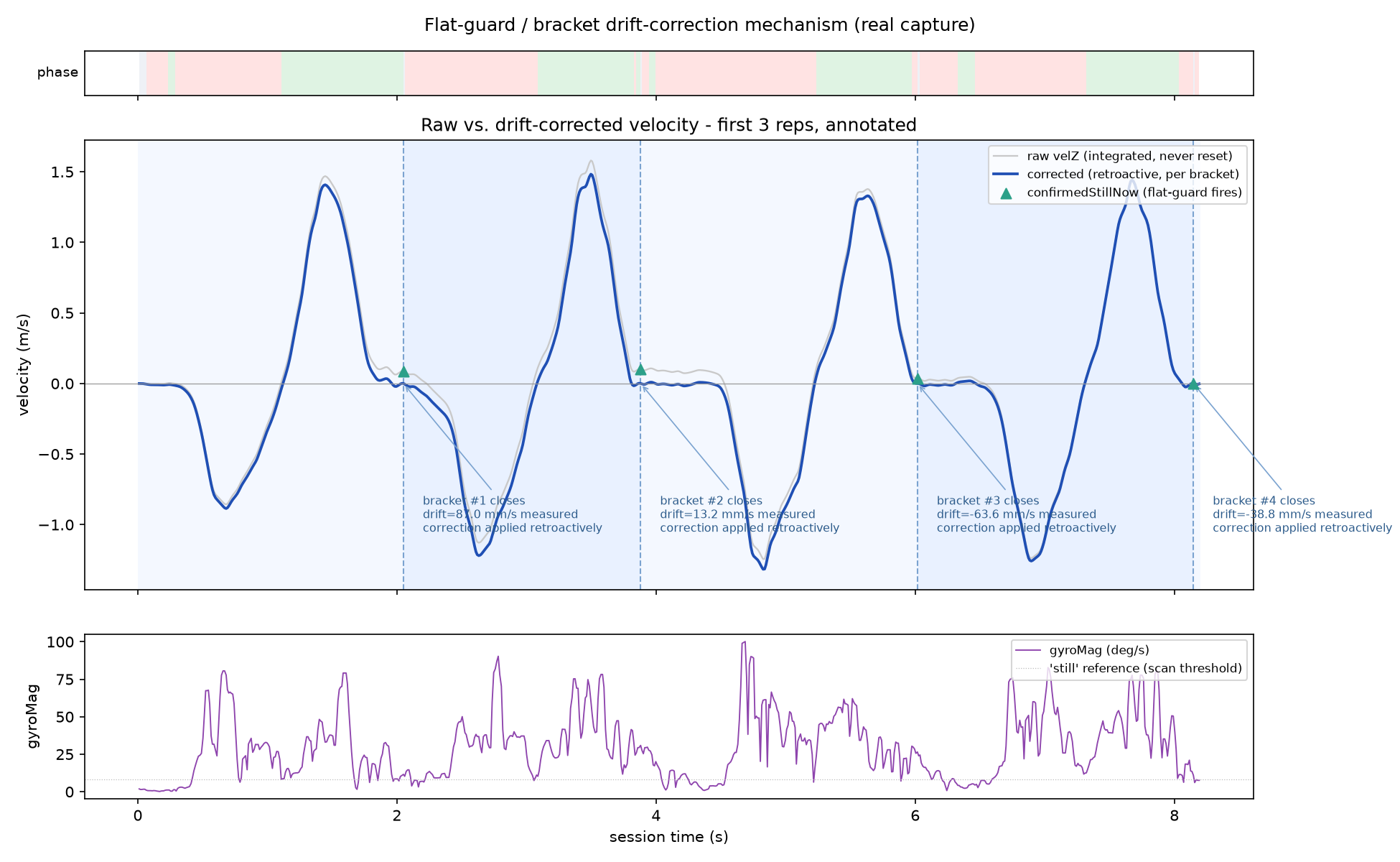
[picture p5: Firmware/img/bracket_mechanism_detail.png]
Bracket close mechanism, annotated, first 3 reps


### Bracket drift correction

A **bracket** is the stretch of samples from one confirmed stillness event to the next. Every sample is appended to a bracket buffer regardless of whether a phase is open (`bracketBuf`, capacity 3000 samples / 30s — a safety cap, not a design target). When the flat-guard condition transitions from false to true (a *rising edge* — not every sample while it stays true, or a long real pause would re-close the bracket on every single sample), `closeBracketFn()` runs:

1. **Measure the drift.** `drift = velZ − baselineRawVel`, where `baselineRawVel` is the raw `velZ` value the *previous* bracket close left behind — not absolute zero. This is what makes the corrected curve continuous across bracket boundaries instead of showing a small "step" at every rep.
2. **Distribute it retroactively and linearly.** Every sample `s` in the closing bracket is corrected as `corrected(t) = velZ(t) − baseline − drift × (t − t0) / (t1 − t0)` — the same formula the app receives via the `CorrectedCurve` BLE characteristic, and the one `tools/vbt_log_viewer.py` uses to reconstruct the plots in this chapter offline from a raw debug log.
3. **Rescore every phase the bracket contained.** Any phase that closed while this bracket was still open was originally reported using a *provisional* estimate (below); it is now rescored against the true measured drift and re-reported with `correctionStatus = Corrected`.
4. **Move the reference forward.** `baselineRawVel` becomes the current `velZ` — the next bracket measures its own drift relative to *this* point, not to zero.

Because the correction for a bracket is only known once it closes — which can be a second or more after the samples inside it were captured — a phase that closes *before* its own bracket does can't wait for the true number. It's scored immediately with a **provisional** estimate instead: an EMA of recently-measured bracket rates (`RuntimeConfig::emaAlpha` — how much a single new measurement moves the running average) extrapolated forward in time, or the rep-based calibration below if that's already available and considered more reliable. It's this same EMA rate, evaluated live every sample as `livePredictedOffset()`, that the flat-guard tests against in the previous section.

**v3.11.26 fix — a noisy short bracket could seed a rate later extrapolated unbounded over a much longer one:** user-reported from a real capture (a heavy/slow deadlift rep) — `velZLive` started diverging from `velZ` about 5 seconds in and kept getting worse, reaching nearly double the raw value before snapping back once the rep reversed. Two compounding causes, both in the EMA path above (the rep-based calibration below was unaffected — `repCalibCount` hadn't reached 2 yet in the diagnosed window). First, `closeBracketFn()` moved `emaRate` by the *same* `emaAlpha` regardless of how long the closing bracket had actually run — a 150ms bracket (noise between two close reps, 15 samples) swung the estimate just as hard as a full 1-2s one, in the diagnosed capture seeding a rate of 0.206 m/s² from that noise alone. Second, `livePredictedOffset()` extrapolated that rate *linearly and without limit* over the elapsed time since the last anchor — fine for a normal rep under a second, but the very next bracket then stayed open 8.95s (a slow eccentric with no still pause to re-anchor it), during which the 0.206 rate compounded to a predicted offset of 0.90 m/s, entirely an artifact of the seed bracket's noise. Fixed with two independent, narrowly-targeted changes, both simulated against the real capture before being implemented (drift-window max error 1.61 → 0.30 m/s, RMS 0.87 → 0.27 m/s; the 145 samples where `velZLive` exceeded 1.0 m/s while `velZ` itself stayed under 0.35 m/s — reported velocity with no corresponding real motion — dropped to zero): `closeBracketFn()` now scales `emaAlpha` down for brackets shorter than 1.0s, so a short noisy bracket can no longer move the EMA nearly as much as a full-length one; `livePredictedOffset()` caps the extrapolated elapsed time at 2.5s, past which the offset freezes at its best estimate instead of continuing to run away — normal re-anchoring still corrects it the instant a real reference point (a genuine pause, or the next bracket close) becomes available.

### Rep-based calibration (bracket-independent)

Bracket correction requires a genuine pause — it has nothing to measure otherwise. A separate, complementary calibration source needs no pause at all: every negative-to-positive zero-crossing of raw velocity (one full descend-then-rise cycle) should, physically, return to very nearly the same position it started from, regardless of how fast or slow that particular rep was. Each valid crossing (`RuntimeConfig::minCrossingExcursionMps`/`minCrossingDurationS` filter out noise) contributes one data point — mean time, net position offset over that cycle — to an incrementally-updated linear regression (`repCalibRate`, `repCalibIntercept`). Once at least two such cycles are available, this calibration is used *in preference to* the EMA bracket rate for provisional scoring, because it keeps improving through a continuous, gapless set (e.g. touch-and-go reps with no true stillness anywhere) where brackets may close rarely or not at all.

### The flat-guard's two-tier design

Even with the live-corrected-estimate fix above, one failure mode remained: during a long stretch with no bracket ever closing, the provisional estimate itself (EMA or rep calibration) can accumulate enough error that the corrected `velZLive` value it produces stays outside `flatGuardMaxVelocityMps` *even while the sensor is genuinely motionless* — not because the sensor is drifting, but because the estimate being used to judge it is wrong, and without a bracket closing, that estimate has no way to correct itself. It's the same underlying failure shape as the raw-vs-corrected fix earlier in this chapter, just moved up one level of indirection.

**v3.11.27 fix — the raw-stillness override almost never fired, and dropping the ceiling wasn't safe either:** through v3.11.26, the safety net for this (`flatGuardOverrideStillTimeS`, 1.0s) watched raw gyroscope/accelerometer stillness instead of `velZLive` — independent of the estimate, but requiring a full, *unbroken* second with every sample in the window under band. User-reported still unresolved on a second real deadlift capture (`STACCO_3`) even after v3.11.26 bounded the drift: the bar's ground contact (unavoidable in a deadlift) is a real, expected deceleration, and `velZ` settled genuinely flat within under a second of it — but the override never fired even once in the whole capture, because post-impact ringdown scatters small noise samples through that window, each one forcing the full second to restart from scratch. A simpler alternative — dropping `flatGuardMaxVelocityMps` from the primary path entirely and trusting the dynamic-window flatness tests alone — was considered and rejected after simulating it against the same capture: at high phase-peak velocity the dynamic window shrinks to as little as 2 samples (20ms), and a smooth velocity curve's acceleration crosses zero at *every* local peak by simple calculus, for a few milliseconds instead of hundreds — with a 2-sample window that momentary crossing at the *top* of a fast rep is indistinguishable from a genuine stop. Confirmed directly in the capture's own first rep: without the ceiling, the engine would have declared "flat" at `t=1.423s` with `velZLive=1.0065 m/s` — the exact peak of a clean 1.27 m/s pull, not a stop. So the ceiling stays on the fast/dynamic-window path (it's load-bearing there), and the override is replaced instead: once a phase is open and `|velZLive|` exceeds `flatGuardMaxVelocityMps`, **both** flatness tests switch from the dynamic window to `RuntimeConfig::velocityOverrideFlatWindowSamples` — a fixed window (30–60 samples, configurable from the app) over the *same* `velZLive`/`worldAccZ` signal the fast path already uses, not raw IMU noise, so an isolated post-impact sample doesn't force a full restart the way the old raw-quiet ring did. Long enough that a genuine pause (flat for hundreds of ms) can't be mistaken for a fast rep's momentary peak (tens of ms), short enough to resolve well inside a second. Verified against both captures before implementing: the wide window correctly does *not* fire at the `STACCO_3` rep-1 peak (actual excursion over the window: 1.01 m/s, nowhere near the 0.08 m/s band it needs), and fires early into the problem stretch that used to run for 8-10 seconds unbounded. Every time it fires it's still flagged in the debug log (`flatGuardOverrideFired`, same field, repurposed) so it can be audited after the fact; `tools/vbt_log_viewer.py` marks these with a red triangle on the overview plot and reports a count in its console summary.

### Live re-anchoring for display

While the flat-guard confirms the sensor still (`confirmedStillNow`), `baselineRawVel` (and the bracket's start time) are kept continuously aligned to `velZ` for the *entire* duration of the pause, not just at the moment the bracket closes. This has two effects from the same mechanism: the value streamed live for the app's real-time graph (`refVelZ = velZ − baselineRawVel`) reads a clean ~0 throughout a real pause instead of sitting on a not-yet-converged residual, and the *next* phase's provisional correction starts from a fresh reference instead of a stale one left over from before the pause began. This never touches `velZ` itself or the buffered bracket samples — only the live display reference.

**v3.11.15 fix — the rep-based calibration needed the same treatment:** the re-anchoring above only ever applied to `baselineRawVel`/`bracketStartT`, which feed the EMA estimate. The rep-based calibration from the previous section has no equivalent — `repCalibRate × sessionT + repCalibIntercept` is a fixed regression over *absolute* session time, and until this fix nothing ever refreshed it between rep cycles. Traced to a real capture where a bracket stayed open for 10.77 seconds spanning three reps, unstuck only by a deliberate manual jolt: because `repCalibCount ≥ 2` after just two valid cycles — true for nearly all of a real set — this calibration, not the EMA, is what `livePredictedOffset()` actually uses almost the entire time, and its estimate kept drifting away from the truth on its own during the stall, since `sessionT` keeps advancing while `repCalibIntercept` stood still. The fix mirrors the EMA re-anchoring exactly, just applied to the regression's intercept: while the sensor is confirmed still, `repCalibIntercept` is recomputed so the formula evaluates to exactly `velZ` at that instant. It leaves the regression's accumulated sums untouched, so the next real rep cycle still refits it properly from scratch — this only keeps the *live* reading correct during the pause in between.

**v3.11.20 fix — a refit itself could jump the live reading, no pause involved:** v3.11.15 fixed the estimate going *stale* during a long stall; it didn't cover the estimate changing *abruptly* at the moment `checkZeroCrossing()` registers a new cycle and calls `refitRepCalibration()` — which happens roughly once per rep once `repCalibCount ≥ 2` is the active estimate, i.e. for most of any real set. Traced to a real capture where the rep counter stalled for 13+ seconds despite continuous movement: `repCalibRate × sessionT + repCalibIntercept` is re-evaluated with the newly-refit coefficients at the *current*, already-large `sessionT` — so even a change in `repCalibRate` too small to matter near the regression's own data (thousandths of a unit) gets multiplied by `sessionT` and can dominate the result, an ordinary consequence of evaluating a freshly-refit line far from the window it was fit against. Confirmed sample-by-sample on 5 consecutive refits in the capture: `velZLive` dropped by 0.17–0.25 m/s in a single ~10ms sample *every time*, always right as the concentric phase was ramping up (raw `velZ` rising smoothly in that same sample) — an artificial dip exactly where the phase engine is most sensitive to direction and magnitude, plausibly behind the cluster of concentric phases that closed just under `minPhaseDurationS` and got silently discarded. Fix: the same continuity principle as v3.11.15, applied at a different trigger — right after `refitRepCalibration()` runs inside `checkZeroCrossing()`, `repCalibIntercept` is nudged so the formula evaluates to exactly what it was an instant before, at the same `sessionT`. Neither `repCalibRate` nor the accumulated sums are touched, so the fit's long-term accuracy (and the next refit's starting point) is unaffected — only the artificial step at the instant of *this* refit is removed from the live reading.

### Correction status and re-reporting

Every reported rep (`RepResult`) carries a `correctionStatus`, and the **same rep can be sent more than once** with the same `repNumber` as its estimate improves — the receiving app is expected to overwrite by `repNumber`, not append:

| Status | Meaning |
|---|---|
| `Provisional` (0) | Scored against the EMA-extrapolated bracket rate; its own bracket hasn't closed yet. |
| `RepCalibrated` (1) | Scored against the rep-based crossing calibration (≥2 valid cycles available), used when no bracket has closed recently. |
| `Corrected` (2) | Scored against a bracket's *measured* drift — the bracket containing this phase has closed. Final; won't be re-reported again. |

A rep's overall status is the *worse* (least certain) of its concentric and eccentric phase statuses.

### Calibration

`calibrateOrientation()` is a blocking ~2 second routine (`CALIBRATION_SAMPLES` samples at `CALIBRATION_SAMPLE_DELAY_MS` apart) that must be run with the device genuinely at rest. It:
- Averages accelerometer readings and hands them to the Madgwick filter's `alignToGravity()`, giving the filter a correct starting orientation instead of assuming the device begins level.
- Averages gyroscope readings to seed the gyro bias (the zero-rate offset at rest).
- Derives this specific accelerometer's real g→m/s² scale factor (`accelScaleG`): at true rest the acceleration vector's magnitude must equal exactly `G`; any deviation is a factory scale/offset error on that particular sensor, not real motion, so the correction factor is computed once and used everywhere gravity is subtracted afterward. Clamped to a ±15% sanity window — outside that range a calibration or movement error during the window is assumed and the ideal `G` is used unmodified instead.
- Rejects individual outlier samples during the averaging window (occasional readings a full order of magnitude above the normal at-rest noise floor have been observed on real hardware, most likely transient I2C/radio contention rather than physical movement) and warns over Serial if the gyroscope range during the whole window suggests the device wasn't actually still.

### Delivering reps and corrected-curve chunks without blocking

Two small FIFO queues sit between this module and BLE, following the same peek/pop pattern for both:

- **Reps** (`pendingReps`, capacity 32) — `peekCompletedRep()` copies the oldest queued rep without removing it; `popCompletedRep()` removes it. `VBT_Quaternions.ino` calls `popCompletedRep()` only *after* `BleServer::sendRepSummary()` actually succeeds (see the BleServer chapter for why this two-step pattern exists) — if delivery fails, the rep just stays at the front of the queue and is retried on the next sample.
- **Corrected-curve chunks** (`chunkQueue`, capacity 220) — a bracket close can produce thousands of corrected samples at once (`enqueueCorrectedCurveChunks()`), far more than fit in one BLE packet, so they're split into fixed-size chunks (`CorrectedCurveChunk::CAPACITY = 20` samples each) and drained the same peek/pop way as reps.

Neither queue ever silently drops data because of a busy or momentarily disconnected link — only the (deliberately generous) fixed queue capacity is a hard limit, and it's sized well above anything observed in real captures.

### `RuntimeConfig` field reference

All fields are adjustable at runtime over the BLE Config characteristic (see the BleServer chapter) and are **not** persisted to flash — the firmware always boots from the compiled defaults (`RuntimeConfig{}`, i.e. the values below).

| Field | Default | Meaning |
|---|---|---|
| `repDirection` | `Up` | Which physical direction counts as the concentric (measured) phase. |
| `maxPlausibleVelocityMps` | 4.0 | Hard clamp on `velZLive`, both directions (v3.11.19; was `velZ` itself through v3.11.18 — see the version note in `MotionTracker.cpp`) — beyond this it's certainly drift, not real motion. |
| `accZBiasIdleStillTimeS` | 0.05 | Consecutive stillness time required before refreshing `accZBias`. |
| `gyroBiasIdleStillTimeS` | 0.3 | Consecutive stillness time required before refreshing the gyroscope bias. |
| `accZBiasGyroMaxDegS` | 12.0 | Gyroscope-magnitude ceiling (deg/s) below which a sample is a candidate for bias updates. |
| `accZBiasAccMagToleranceMps2` | 0.12 | Half-width of the excursion band `\|acceleration\|` must stay within, over a short sliding window, for a sample to be a bias-update candidate (v3.11.11+; was an absolute distance from `G` before). |
| `flatGuardMaxVelocityMps` | 0.20 | Absolute ceiling on corrected live velocity beyond which the flat-guard can never fire while a phase is open. |
| `velocityOverrideFlatWindowSamples` | 45 | Fixed flatness window (samples) used once `\|velZLive\|` exceeds `flatGuardMaxVelocityMps` — replaces the dynamic window for BOTH flatness tests above in that case (v3.11.27, see [The flat-guard's two-tier design](#the-flat-guards-two-tier-design)). Range 30–60. |
| `velocityFlatBandMps` | 0.04 | Max excursion allowed in the recent velocity window to count as flat. |
| `maxVelocityFlatWindowSamples` / `minVelocityFlatWindowSamples` | 30 / 2 | Dynamic window bounds for the velocity flatness test. |
| `accelerationFlatBandMps2` | 0.3 | Max per-sample deviation from zero in the recent acceleration window to count as flat. |
| `maxAccelerationFlatWindowSamples` / `minAccelerationFlatWindowSamples` | 30 / 2 | Dynamic window bounds for the acceleration flatness test. |
| `windowSaturationPeakVelocityMps` | 0.8 | Peak velocity above which both windows above saturate to their minimum size. |
| `phaseStartVelocityMps` | 0.2 | Corrected-velocity threshold for opening a new phase. |
| `minPhaseDurationS` | 0.35 | Minimum phase duration; shorter ones are discarded as noise. |
| `maxPhaseDurationS` | 5.0 | Timeout after which an open phase is force-closed. |
| `phaseLookbackSamples` | 5 | How many already-buffered samples a newly opened phase backfills, so its start isn't clipped to the exact threshold crossing. |
| `reversalConfirmSamples` | 3 | Consecutive opposite-direction samples required to confirm a reversal close. |
| `emaAlpha` | 0.3 | Ceiling weight of a single newly-closed bracket's rate on the running EMA drift-rate estimate — scaled down for brackets under 1.0s long (v3.11.26, see the version note below), so a short noisy bracket moves the estimate less than a full-length one. |
| `minCrossingExcursionMps` | -0.03 | Minimum (negative) excursion required for a zero-crossing to count toward rep-based calibration. |
| `minCrossingDurationS` | 0.3 | Minimum cycle duration to count toward rep-based calibration. |

**v3.11.24 — `debugLogEnabled` removed:** it used to be a field in this table (a BLE-only, RAM-only switch for the raw serial log below), but that made it a recurring source of confusion — it reset to off on every power cycle just like calibration, and there was no way to turn it on at all from a serial-only tool (`tools/vbt_live_monitor.py`) with no BLE access, since it's the phone app that would have to set it. It's now decided automatically: see [Lab data capture](#lab-data-capture-serial-log) below.

### Lab data capture (serial log)

The firmware prints this log automatically whenever a USB-serial connection is open (v3.11.24 — `serialLogActive()` in `MotionTracker.cpp`, `(bool)Serial` under the hood, the same check `deviceConnected()` uses for the status LED; before this version it was gated on the now-removed `debugLogEnabled` Config field instead). Bracketed by `REC_START`/`REC_STOP` markers with each row type's CSV header printed once at the start of a recording:

- **`S,` rows** — one per sample at the full 100Hz internal rate (`logSampleCsv()`): raw sensor/orientation data, `velZ` (raw, never reset), `refVelZ` (live re-anchored display value), `velZLive` (the corrected estimate the engine actually makes decisions on), the current rep-calibration rate/intercept/count, and the four per-sample event flags (`velClamped`, `bracketClosed`, `confirmedStillNow`, `flatGuardOverrideFired`).
- **`R,` rows** — one per completed rep (re-printed as its correction status improves, per [Correction status](#correction-status-and-re-reporting) — the last one for a given `rep` is authoritative).
- **`B,` rows** — one per bracket close (`bracketId, t0, t1, baseline, drift, rate, emaRateAfter, basisTotal`). Together with the `S,` rows in `[t0, t1]`, this is everything needed to reconstruct the corrected curve offline with the exact formula from the [bracket drift correction](#bracket-drift-correction) section above — this is what `tools/vbt_log_viewer.py` does to produce both images in this chapter.
- **`P,` rows** (v3.11.18) — one per phase close *attempt* (`phaseId, repNumber, phaseType, closeReason, durationS, sampleCount, discarded, reported`), including ones silently discarded for being too short (`reported=0`) — those never produced an `R,` row before this, so there was no way to see them at all. `closeReason` is `0`=flat, `1`=reversal, `2`=timeout. Two consecutive `P,` rows with the same-sign `phaseType` and no rep-completing close between them is the signature of a spurious same-direction split (see the v3.11.18 fix note in `MotionTracker.cpp` for the bug this caused before it was fixed) — this row makes that directly visible instead of requiring it to be reconstructed from the `S,` rows' `state` column, which can't distinguish "closed and immediately reopened the same direction" from "never actually closed".

This is meant for a laptop actively reading the serial port during a capture session — leaving the sensor plugged into a USB charger with nothing reading the port has the same real CPU/power cost every cycle as an intentional capture, and writing to a serial buffer that nobody is draining can, on some platforms, stall the loop and delay sampling itself; unplug it (or close the serial connection) for normal untethered training. The decimated BLE stream (this app's live graph, see `StreamPacket` in the BleServer chapter) is automatically disabled while a serial connection is open, since it would otherwise duplicate the same data at a lower rate over a separate channel competing for the same `loop()` cycle — the two are mutually exclusive by construction, not by a setting either side has to remember to flip.
## BleServer

Implements the device's Bluetooth Low Energy peripheral role: one custom service for streaming and control, plus the standard Battery and Device Information services, plus buttonless DFU for over-the-air firmware updates. This is the only file that talks to the Bluefruit52Lib / SoftDevice BLE stack directly — the rest of the firmware only calls the functions declared in `BleServer.h`.

### Custom service characteristics

| Characteristic | Properties | Purpose |
|---|---|---|
| Stream | Notify | Decimated live telemetry (acceleration, velocity, position, orientation, phase state), sent only while tracking is active. `refVelZ` here is always the raw, live-re-anchored value — never the retroactively-corrected one (see CorrectedCurve below). |
| RepSummary | Notify | One packet per completed rep — see [Correction status](#correction-status-and-re-reporting) in the MotionTracker chapter for why the same rep can be sent more than once. |
| CorrectedCurve | Notify | Blocks of drift-corrected velocity for a time range already streamed as raw via Stream, sent when the bracket covering that range closes. The client is expected to redraw that portion of its live graph in place. |
| SystemStatus | Read/Notify | Calibrated / tracking-active flags. Pushed automatically on every state change and on every new connection, and independently readable at any time. |
| Command | Write | `0x00` STOP, `0x01` START, `0x02` CALIBRATE. |
| Config | Read/Write | Runtime-adjustable algorithm parameters, mirroring `RuntimeConfig` (see the MotionTracker chapter). Not persisted — the app is responsible for re-sending the last-used configuration on every new connection if it differs from the compiled defaults. |

Battery and firmware version use the *standard* Bluetooth SIG services instead of custom ones (`BLEBas` / Battery Service 0x180F, `BLEDis` / Device Information Service 0x180A), so any generic BLE tool — not just this project's own app — can read them without knowing this project's custom UUIDs.

Buttonless DFU (`BLEDfu`) is a thin bridge: writing to it reboots the device into the Adafruit factory bootloader, which exposes the real Nordic Secure DFU service for the actual firmware transfer. That transfer is handled entirely by the stock bootloader and a DFU-aware app library (e.g. `nordic_dfu` on Flutter) — this file never implements any part of the transfer protocol itself.

### Wire format

All physical quantities are sent as **fixed-point integers**, not floats: `real_value = raw / scale`. This halves the payload compared to 32-bit floats and sidesteps any float-endianness/format concerns on the client side. Every packet struct is declared with `#pragma pack(push, 1)` so its C++ layout exactly matches the bytes sent over the wire, with no compiler-inserted padding — a client on any platform can parse it directly from the raw bytes as long as it respects little-endian byte order (the platform's native order here).

The full byte-exact layout of every characteristic — UUIDs, per-field byte offsets, scales, and worked decode examples — is maintained separately in **[`BLE_PROTOCOL.md`](BLE_PROTOCOL.md)**, written specifically so a third-party client can be implemented from that document alone, without reading any firmware source. This section stays a quick summary:

| Characteristic | Size | Purpose |
|---|---|---|
| `Stream` | 37 B, Notify | Live telemetry, raw `refVelZ` |
| `RepSummary` | 17 B, Notify | One packet per completed rep; re-sent as `correctionStatus` improves |
| `CorrectedCurve` | 53 B, Notify | Retroactively drift-corrected velocity, in chunks, on each bracket close |
| `SystemStatus` | 2 B, Read/Notify | `calibrated` / `trackingActive` flags |
| `Command` | 1 B, Write | `0x00` STOP, `0x01` START, `0x02` CALIBRATE |
| `Config` | 38 B, Read/Write | `RuntimeConfig` mirror, not persisted |
| Battery Service (standard, `0x180F`/`0x2A19`) | 1 B, Read/Notify | 0–100% |
| Device Information (standard, `0x180A`/`0x2A26`) | variable, Read | Firmware version, `"MAJOR.MINOR.PATCH"` |

### Why RepSummary uses Notify, never Indicate

BLE offers two ways to push data without the client explicitly polling: Notify (fire-and-forget) and Indicate (the peripheral waits for a GATT-level acknowledgment from the client before the transfer completes). RepSummary uses Notify exclusively. The Bluefruit52Lib implementation of `indicate()` blocks the *entire* `loop()` — and therefore all IMU sampling — until the client's acknowledgment arrives, with **no timeout at all**: it waits on a FreeRTOS semaphore with `portMAX_DELAY`. If the connected phone is ever slow to acknowledge a single packet, the whole device freezes until it does (in the worst case, until the hardware watchdog forces a reset). This is not a theoretical concern — it was observed causing rep reports to arrive late or go missing entirely on real hardware.

`sendRepSummary()` returns `true` only if the notify was actually sent (connected, and the BLE stack's internal notify buffer wasn't full); it returns `false` otherwise, without blocking. The caller (`VBT_Quaternions.ino`) uses `MotionTracker::peekCompletedRep()`/`popCompletedRep()` together with this return value: a rep is only removed from the pending queue once its notify has actually gone out, so a momentarily busy or disconnected link never loses a rep — it's retried on the next sample instead.

### Command and Config write handling

Both `command_write_callback()` and `config_write_callback()` run inside the BLE stack's own scheduler context, not the main `loop()`. They do the minimum possible there — set a flag or stash a pending value — and let `loop()` perform the actual state change on its own schedule via the `take*Requested()` / `takeConfigUpdate()` functions, each of which consumes (returns true for) at most one pending event per call.

A config write also immediately echoes the received value back into the characteristic's own Read-accessible value (`writeConfigCharacteristic()`), so a Read performed right after a Write already reflects it, even before `loop()` has consumed `takeConfigUpdate()`.

### Connection setup

On every new connection, `connect_callback()` requests the largest MTU the client will grant (up to 247 bytes) and a data length update — `StreamPacket` alone is 37 bytes, larger than the default 23-byte MTU, so this negotiation is required before streaming can work at all. `Bluefruit.configPrphBandwidth(BANDWIDTH_MAX)` must be called before `Bluefruit.begin()` to reserve enough bandwidth/RAM for that large MTU and for a sufficiently deep notification queue to sustain ~20Hz streaming.

## MadgwickAHRS

Implements Sebastian O.H. Madgwick's open, public-domain AHRS (Attitude and Heading Reference System) filter, restricted to the 6DOF case (accelerometer + gyroscope, no magnetometer). It converts raw IMU samples into a stable orientation estimate, expressed as a unit quaternion.

### Why a Madgwick filter

A gyroscope alone gives an accurate short-term rate of rotation, but integrating it over time drifts unboundedly. An accelerometer alone gives a noisy but drift-free reference to "down" (gravity) when the sensor isn't accelerating hard in other directions. The Madgwick filter fuses the two: it integrates the gyroscope to track orientation moment-to-moment, then nudges that estimate toward the direction implied by the measured gravity vector, using a gradient-descent correction step. The result is an orientation quaternion that tracks fast rotations accurately (thanks to the gyro) without drifting over time (thanks to the accelerometer correction). This is the standard, widely-used open Madgwick AHRS algorithm — this project uses it because it's lightweight enough for a microcontroller, well understood, and sufficient without a magnetometer for a device that only needs relative orientation during a lifting movement, not absolute heading.

### Public interface

- `void reset()` — sets the internal quaternion back to identity (`[1,0,0,0]`, i.e. no rotation).
- `void alignToGravity(float ax, float ay, float az)` — one-shot calibration helper. Given an accelerometer reading taken while the device is stationary, it computes the quaternion that rotates the body frame's Z axis onto the measured gravity direction, and sets that as the current orientation. Call this once, at rest, before starting continuous `update()` calls, so the filter starts from a sensible initial orientation instead of assuming the device begins perfectly level.
- `void update(float gx, float gy, float gz, float ax, float ay, float az, float dt, float beta)` — the main filter step, called once per IMU sample. `gx/gy/gz` are gyroscope rates (radians/second), `ax/ay/az` are accelerometer readings (any consistent unit, since they're normalized internally — gravity units such as g are typical), `dt` is the elapsed time since the last update in seconds, and `beta` is the filter's gain: how strongly the accelerometer correction pulls the gyro-integrated estimate back toward gravity. A higher `beta` corrects drift faster but is noisier and more sensitive to real (non-gravity) accelerations; a lower `beta` trusts the gyro more and drifts more slowly-but-surely. If the accelerometer reading is exactly `[0,0,0]` (e.g. a sensor fault), `update()` skips the correction step and falls back to pure gyro integration for that sample.
- `float q0() / q1() / q2() / q3()` — read-only accessors for the current orientation quaternion, in scalar-first order (`q0` is the scalar/real part; `q1,q2,q3` are the vector/imaginary part).

### Algorithm shape (for anyone modifying it)

Each `update()` call:
1. Computes the gyroscope-only rate of change of the quaternion (`qDot1..4`).
2. If the accelerometer reading is non-zero, normalizes it and computes the gradient of an error function representing the mismatch between the gravity direction implied by the current quaternion estimate and the direction actually measured by the accelerometer. This gradient is normalized and subtracted from the gyro-derived rate of change, scaled by `beta` — this is the sensor-fusion correction step.
3. Integrates the (possibly corrected) rate of change over `dt` to get the new quaternion.
4. Re-normalizes the result, since numerical integration would otherwise slowly drift away from a valid unit quaternion.

The algebra in steps 1–2 (the `s0..s3` gradient terms) is the closed-form gradient of the Madgwick error function for the 6DOF case; it's the standard published derivation and should not be modified without re-deriving it from the original Madgwick paper/reference implementation. Safe places to adjust behavior are the `beta` value passed in by the caller (tune responsiveness vs. drift) and the calibration flow around `alignToGravity()`.
## PowerManager

Handles the physical power switch, the nRF52840's hardware watchdog, and entry into deep sleep (System OFF). Everything here is nRF52840-specific and talks directly to Nordic SDK registers via `nrf_gpio.h` and the SoftDevice (`bluefruit.h`).

### Public interface

- `void begin()` — call once from `setup()`. Configures `WAKE_PIN` as an input with pull-up, captures and clears `NRF_POWER->RESETREAS` (so later code can inspect the reset cause), and arms the hardware watchdog (WDT) with an 8-second timeout.
- `bool wakeSwitchClosed()` — returns true when the power switch is closed (pin pulled to GND). The switch is wired active-low.
- `void goToSleep()` — puts the device into System OFF, the nRF52840's lowest-power sleep mode. **Never returns.** Waking from System OFF is not a resume — it's a full chip reset, so `setup()` runs again from scratch.
- `uint32_t lastResetReason()` — returns the `RESETREAS` value captured in `begin()`, before anything else could touch it. Useful for diagnosing whether the last boot came from a fresh power-on, a watchdog reset, a wake from System OFF, etc.
- `void feedWatchdog()` — must be called once per `loop()` iteration. Never call it inside a blocking wait/error loop.

### Hardware watchdog (WDT)

The WDT is a safety net against firmware lockups (crashes, hard faults, I2C/BLE/USB hangs) that would otherwise leave the device unresponsive until the battery is physically disconnected. Key behaviors:

- Once started, the nRF52840 WDT **cannot be stopped in software** — only a reset clears it. `begin()` arms it once for the life of the program.
- It keeps counting while the CPU is idle/WFI (`CONFIG.SLEEP = Run`), since `delay()` and the BLE stack rely on that idle state between events, and a genuine hang must still be catchable there.
- It pauses while a debugger holds the CPU at a breakpoint (`CONFIG.HALT = Pause`), so normal debugging doesn't trigger spurious resets.
- The timeout is 8000 ms — comfortably above the longest normal blocking stretch in the firmware (up to 3000 ms waiting on Serial in `setup()`, or 2000 ms during `MotionTracker::calibrateOrientation()`), while still being short enough to recover quickly from a real hang.
- The WDT is **not retained across System OFF** — it powers down along with the rest of the chip, so `goToSleep()` doesn't need to stop it explicitly. On wake (which is always a full reset), `begin()` re-arms it from zero.

If the watchdog fires, it forces a full reset — equivalent to a power cycle but automatic. This is treated as an acceptable recovery mechanism even for loops that would otherwise need explicit error handling (e.g. a transiently stuck IMU I2C bus can resolve itself after the forced restart).

### Deep sleep (System OFF)

`goToSleep()`:
1. Turns off the status LED and flushes a log message.
2. Reconfigures `WAKE_PIN` as a GPIO **sense input** (`nrf_gpio_cfg_sense_input`, pull-up, sense LOW) — this is what lets the chip wake from System OFF when the switch is closed again.
3. Calls `sd_power_system_off()` — **not** a direct write to `NRF_POWER->SYSTEMOFF`. With the BLE SoftDevice active, direct writes to that register are silently blocked/ignored in a non-deterministic way (the SoftDevice guards it), so `sd_power_system_off()` is the only correct, SoftDevice-safe entry point. This requires `Bluefruit.begin()` to have already run before `goToSleep()` is called.
4. Never returns; the trailing `while(1)` is unreachable and only there for the compiler.

Because the sense/DETECT wake mechanism only works for waking from a true System OFF state, a device that hangs *before* reaching `sd_power_system_off()` (e.g. mid-crash) is not truly asleep and won't respond to the switch — this is exactly the failure mode the watchdog is designed to recover from.

### Constants

- `WAKE_PIN` (see `Config.h`, `D6`): power switch input, active-low (closed = GND = device on).
- `WATCHDOG_TIMEOUT_MS = 8000`: see rationale above.
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

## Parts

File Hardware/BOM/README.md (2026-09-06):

# Bill of Materials

Full parts list for one ODKI VBT unit: see [`bom.csv`](bom.csv) for the structured table (description, quantity per unit, key specs, approximate unit cost). This page adds the technical detail that doesn't fit comfortably in a spreadsheet cell.

Where to buy each part is up to you — specs below are what to match, not a specific listing to use. Magnets and the power switch are typically sold in bulk packs (e.g. 50+ magnets, 100+ switches); only a few units per pack are needed per sensor, so the realistic per-unit cost is a small fraction of the pack price. Prices in `bom.csv` are rough, observed ranges, not a quote — shop around, especially for the microcontroller, where equivalent listings for the same board have been seen varying quite a bit in price between sellers.

## LiPo battery (1 per unit)

3.7V nominal, 400 mAh (1.48 Wh) capacity, Li-Po size code **602035** (6mm thick x 20mm wide x 35mm long). CE certified. **Make sure whatever cell you use includes a built-in protection chip** (over-charge, over-discharge, and short-circuit protection) — the reference cell does, and the two leads are soldered directly to the XIAO board's `B+`/`B-` pads (see [`Hardware/Instructions`](../Instructions/)) with no separate protection circuit in between, so an unprotected bare cell would have nothing else guarding it. This is the cell referenced throughout `Firmware/DOCUMENTATION.md` (BatteryMonitor chapter) for voltage reading, charge percentage, and auto-calibration — any similarly-sized single-cell 3.7V protected LiPo should work, but the discharge curve assumed by `BatteryMonitor::voltageToPercent()` (3.30V = 0%, 3.60V = 10%, 4.20V = 100%) is tuned for a typical LiPo chemistry and may need adjusting for a very different cell.

## Microcontroller (1 per unit)

**Seeed Studio XIAO nRF52840 Sense** — the reference design's MCU + IMU + BLE module, all-in-one. Official specifications (Seeed Studio wiki, more reliable than any individual listing's page):

- Nordic nRF52840, ARM Cortex-M4 32-bit processor with FPU, 64 MHz
- Bluetooth 5.0/5.4, BLE Mesh, NFC
- 256 KB RAM, 1 MB internal flash + 2 MB onboard flash
- Onboard 6-axis IMU: **LSM6DS3TR-C** (accelerometer + gyroscope) — this exact part is what `MotionTracker.cpp` talks to over I2C; a substitute board would need firmware changes, not just a BOM swap
- Onboard PDM digital microphone (unused by this project's firmware, but present on the "Sense" variant)
- Integrated LiPo charge/discharge management (the BQ25100 chip `BatteryMonitor.cpp` reads charge status from)
- USB-C connector, single-sided surface-mount components
- Standby power consumption < 5µA
- Dimensions: **21mm x 17.8mm** (the classic XIAO form factor) — note that some listings display shipping/package dimensions instead of the board's own; 21 x 17.8mm is the board itself, confirmed against Seeed's own wiki.

## Neodymium magnets (3 per unit)

Round disc, **10mm diameter x 2.2mm thick** (±0.1mm tolerance), neodymium, ~2kg pull force per magnet. Used for the barbell-mount attachment — press-fit (plus a drop of glue) into 3 blind pockets molded into [`case-bottom`](../CAD/) — rather than a mechanical clip.

## Power switch (1 per unit)

**SPDT slide switch** (1-pole 2-throw, 3-pin, 2-position), panel-mount, vertical slide actuation, DC 50V / 0.5A rated, model SS12D00-G3. Body without pins/knob: 8 x 4 x 3.8mm; overall with knob: 8 x 4 x 10mm; pin spacing 2.54mm (breadboard-standard). This is the physical power switch `Firmware/DOCUMENTATION.md`'s PowerManager chapter describes as wired to `WAKE_PIN` (`Config.h`, `D6`) and GND, active-low — any SPDT switch of a similar size fits the same wiring, this is just the specific one used in the reference build.

## Hookup wire (2 per unit)

Generic stranded hookup wire, ~26-30AWG, roughly 5-10cm per length — connects the power switch's two relevant pins to `WAKE_PIN` and GND. No specific product; any reel of thin stranded wire works, these are typically leftover offcuts rather than a dedicated purchase.

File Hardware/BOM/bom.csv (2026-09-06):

Component | Qty per unit | Key specs | Approx. unit cost (EUR)
LiPo battery | 1 | 3.7V nominal, 400 mAh (1.48 Wh), Li-Po size code 602035 (6mm[T] x 20mm[W] x 35mm[L]), CE certified, must include built-in overcharge/overdischarge/short-circuit protection chip | ~3.65-4.50 (sold in 2/5/10-pack bundles)
Microcontroller | 1 | Seeed Studio XIAO nRF52840 Sense - Nordic nRF52840 (ARM Cortex-M4, 64MHz), Bluetooth 5.0/5.4 + BLE Mesh + NFC, 256KB RAM, 1MB internal + 2MB onboard flash, onboard 6-axis IMU (LSM6DS3TR-C), onboard PDM microphone, integrated LiPo charge/discharge management, USB-C, standby <5uA, 21mm x 17.8mm | ~14-52 (price varies significantly by seller - shop around)
Neodymium magnet | 3 | Round disc, 10mm diameter x 2.2mm thick (+/-0.1mm), ~2kg pull force per magnet | ~0.21 (from a 52-pack + 2 steel plates at ~10.98)
Power switch | 1 | SPDT slide switch (1P2T, 3-pin, 2-position), panel-mount vertical slide, DC 50V / 0.5A rated, model SS12D00-G3, body without pins/knob 8x4x3.8mm, overall with knob 8x4x10mm, pin spacing 2.54mm | ~0.05 (from a 200-pack at ~9.99)
Hookup wire | 2 | Generic stranded hookup wire, ~26-30AWG, ~5-10cm each - connects the power switch to WAKE_PIN and GND (see Firmware/DOCUMENTATION.md, PowerManager chapter) | negligible (offcuts from any reel)

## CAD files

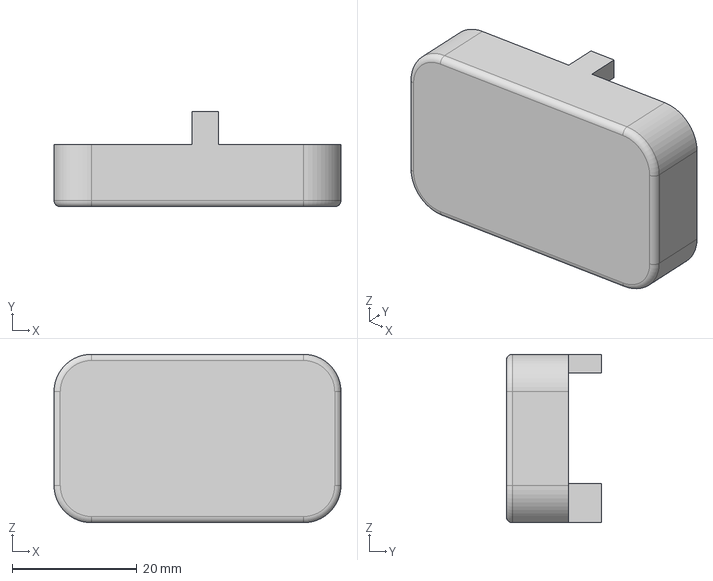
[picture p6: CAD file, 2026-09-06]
Hardware/CAD/case-bottom.step
46.0 x 15.3 x 27.0 mm

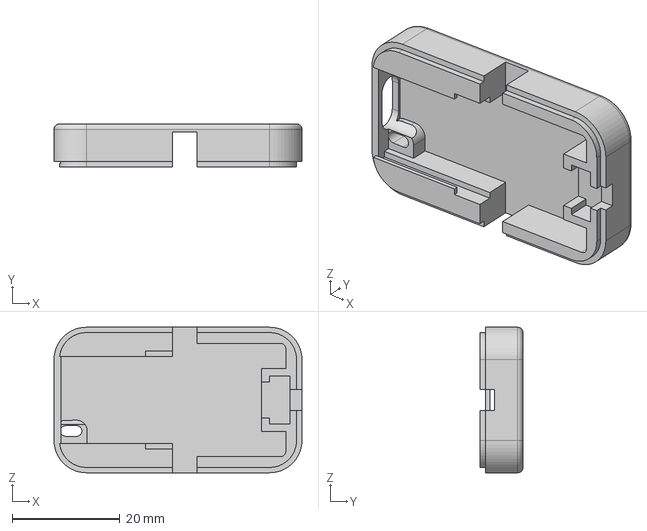
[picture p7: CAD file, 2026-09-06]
Hardware/CAD/case-top.step
46.0 x 8.00 x 27.0 mm

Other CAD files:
Hardware/CAD/case-bottom.f3d
Hardware/CAD/case-bottom.stl
Hardware/CAD/case-top.f3d
Hardware/CAD/case-top.stl

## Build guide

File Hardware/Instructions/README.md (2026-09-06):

# Assembly Instructions

Step-by-step guide to build one ODKI VBT unit from the parts in [`../BOM`](../BOM/) and the enclosure files in [`../CAD`](../CAD/), ending with a working, glued-shut unit ready for normal use.

## ⚠️ Before you start

This guide assumes you're already comfortable **soldering**, **handling a LiPo battery safely** (short-circuiting, puncturing, or reverse-wiring one can cause a fire), and **flashing firmware onto a bare development board** with the Arduino IDE. If any of that is unfamiliar, get help from someone who has done it before, or practice on scrap hardware first — this is not a beginner-friendly first electronics project.

This design and these instructions are provided as-is, under the terms of [LICENSE-HARDWARE](../../LICENSE-HARDWARE) and [LICENSE-FIRMWARE](../../LICENSE-FIRMWARE) (no warranty of any kind). Building and assembling a unit from them is entirely at your own risk — the author/ODKI accepts no responsibility for any damage to your components, injury, fire, or other loss resulting from it.

## What you need

- All parts from the [BOM](../BOM/): battery, Seeed XIAO nRF52840 Sense, 3 neodymium magnets, power switch, ~4cm of thin hookup wire (x2).
- The two printed case bodies from [CAD](../CAD/): `case-top` and `case-bottom`.
- A soldering iron + solder.
- Cyanoacrylate (superglue) — a small amount for the magnets, a bit more for the final case closure.
- A computer with the Arduino IDE, to flash the firmware (see step 3).
- The ODKI VBT companion app (see [`../../Apps`](../../Apps/)), to run the functional test in step 7.

## 1. Wire the power switch

The switch is used as a plain 2-position on/off contact: only 2 of its 3 pins are used — the **center (common) pin** and **one outer pin**. The third pin stays unused.

1. Cut two lengths of hookup wire, roughly 4cm each.
2. Solder one wire between the XIAO's **GND** pad and the switch's **outer** pin.
3. Solder the other wire between the XIAO's **D6** pad and the switch's **center (common)** pin.

This is the exact pin the firmware calls `WAKE_PIN` (see `Config.h` / `Firmware/DOCUMENTATION.md`, PowerManager chapter) — sliding the switch closed pulls it to GND, which is how the firmware later knows to stay awake instead of going to sleep.

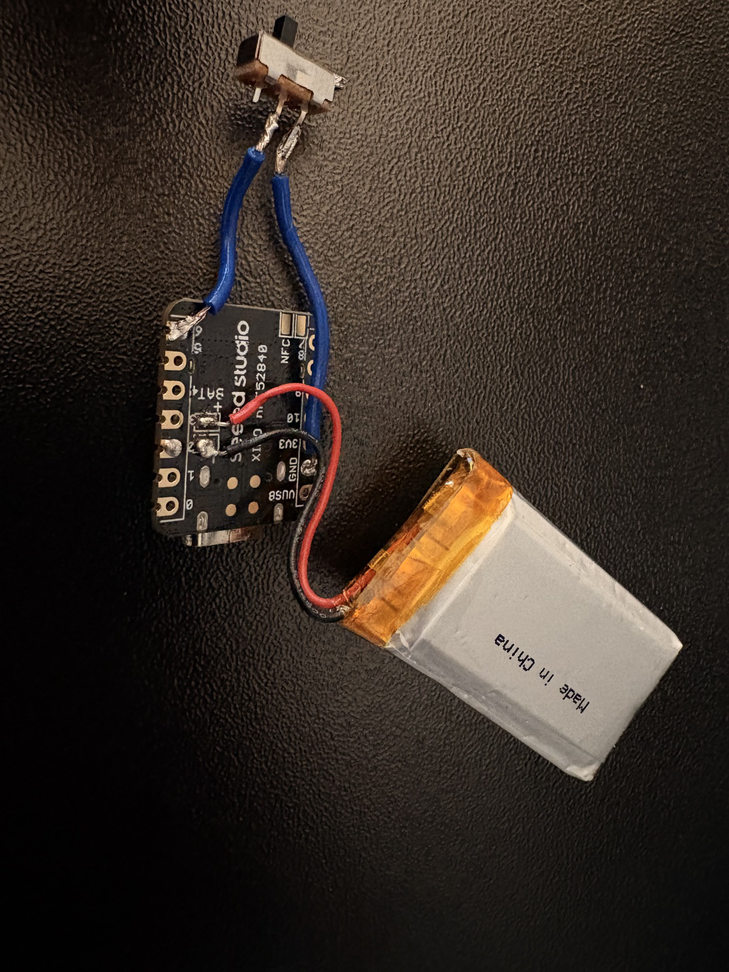
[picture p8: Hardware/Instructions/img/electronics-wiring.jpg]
Switch and battery wired to the XIAO board


## 2. Connect the battery

Solder the battery's two leads directly to the **B+ / B-** pads on the underside of the XIAO board.

**Double-check polarity before soldering** — match the leads against the pads' silkscreen markings (or the official [Seeed XIAO nRF52840 Sense pinout diagram](https://wiki.seeedstudio.com/XIAO_BLE/) if the marking isn't clear). Reversed polarity on a LiPo connection can damage the board or the battery.

As soon as this connection is made, **the board powers on** — at this point nothing is managing sleep/wake yet (that's firmware behavior, step 3), so it will simply stay on, switch position or not, until it's flashed.

## 3. First firmware flash

Flash the ODKI VBT firmware now, following the Arduino IDE setup in the [main README](../../README.md#getting-started) (`Seeeduino:nrf52` board package, board `xiaonRF52840Sense`, `Seeed Arduino LSM6DS3` library) and `Firmware/DOCUMENTATION.md` for what each file does.

Once flashed, the switch actually does something: closed = powered on, open = deep sleep (see the PowerManager chapter in `Firmware/DOCUMENTATION.md`). Slide it open, confirm the board goes quiet, then close it again before continuing.

## 4. Prepare `case-bottom`: magnets + battery

`case-bottom` has 3 round pockets sized for the magnets, in the floor of the same compartment that holds the battery. A small integrated post inside this compartment keeps the battery pinned in place once everything is seated — it also has a second job in step 6 below.

1. Press the 3 magnets into their pockets. Add a small drop of superglue to each before/as you seat them — the fit is snug, but glue keeps them from ever working loose in use.
2. Let the glue set, then place the battery into the same compartment, on top of the magnets, against the post.

## 5. Mount the electronics in `case-top`

Slide the XIAO board (now wired to the switch and the battery) into `case-top` along its internal rail, in the direction that brings the board's USB-C connector up to the cutout in the short end wall — that's what lets the finished, glued unit be charged normally over USB without ever opening it again (re-flashing through the same port is also possible, but only as a fallback: normal firmware updates go over BLE instead). The **opposite** short end has its own dedicated recess for the switch, so it stays operable from outside once the case is closed.

Don't force the board all the way in yet if you're about to plug in a USB cable (e.g. to double check the flash from step 3) — pushing a cable in can push the board back out of the rail. That's exactly what `case-bottom`'s post (step 4) is there to prevent, but only once the two halves are actually joined — see the next step.

| Battery lifted, board + switch seated in the case | Battery seated in place |
|---|---|
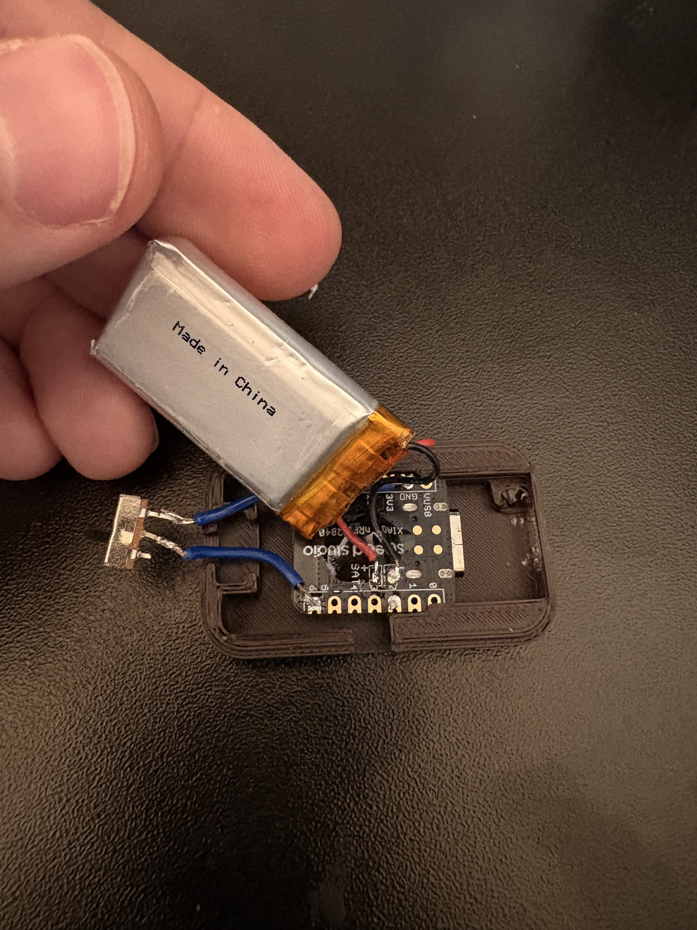
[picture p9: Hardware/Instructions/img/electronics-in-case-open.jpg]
XIAO board and switch seated in the case, battery lifted aside
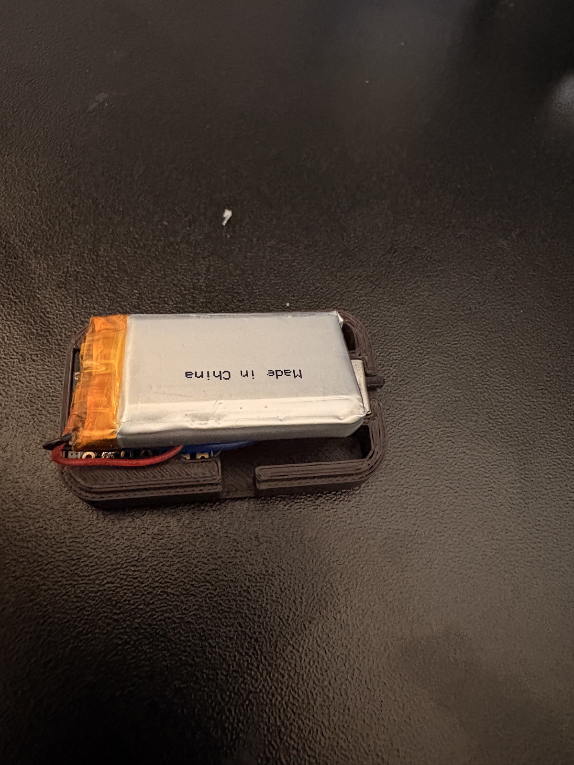
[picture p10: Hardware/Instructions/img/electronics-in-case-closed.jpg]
Battery seated in place over the board
|  |  |

## 6. Close the case (provisionally)

The two halves aren't snap-fit or screwed — the only thing that ever holds them together is the superglue in the final step. For now, don't glue anything yet: just hold the two halves closed (by hand, a rubber band, or a strip of tape) — enough that `case-bottom`'s post backs up the XIAO board against the rail, and everything sits in roughly its final position for the test below.

## 7. Functional test

With the case closed (provisionally) and the switch on, install the companion app and check everything below **before gluing anything**:

- [ ] **LED status** — right after power-on, the status LED blinks red (not connected to the app yet), visible through the small oval window on top of `case-top`. See the StatusLED chapter in `Firmware/DOCUMENTATION.md` for the full state table.
- [ ] **BLE connection** — the app finds the device when scanning, and connects to it successfully. LED should switch from blinking red to solid red (connected, not yet calibrated).
- [ ] **Calibration** — run the app's calibration step (device held still). LED should switch to solid green (calibrated, idle).
- [ ] **Live streaming** — start tracking in the app (LED goes solid blue) and move the device: live velocity data should appear and update in real time, not freeze or stay at zero.
- [ ] **Data sanity** — velocity reads ~0 while the device is genuinely still, rises and falls smoothly and in the expected direction as you move it, and a rep gets detected and reported in the app when you perform one. No wild spikes, NaNs, or values stuck at a clamp.

If **any** of these fail, open the case back up and check the two solder joints from steps 1–2 before assuming it's a firmware issue.

## 8. Permanent assembly

Once every check above passes, open the case one last time, apply cyanoacrylate along the mating edges of `case-top` and `case-bottom`, and close them together for good. From this point on the unit is sealed — see the note in [`../CAD/README.md`](../CAD/README.md) about what that means for future battery replacement.

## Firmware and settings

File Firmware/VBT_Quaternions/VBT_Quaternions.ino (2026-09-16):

// Part of the ODKI VBT Firmware
// Copyright (C) 2026 Lodovico Cortelazzo
//
// Licensed under the GNU General Public License, Version 3 (this
// specific version only, not "or any later version"), modified by the
// Commons Clause License Condition v1.0 -- see LICENSE-FIRMWARE in the
// repository root for the full text of both. In short: you may use,
// study, modify, and share this file (including a modified version) for
// non-commercial purposes; you may not sell it, or a product/service
// substantially derived from it, without a separate agreement with the
// copyright holder.
//
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
/*
  VBT Rep Counter & Velocity Estimator - v3 (BLE)
  Target: Seeed XIAO nRF52840 Sense (integrated LSM6DS3TR-C IMU)

  The code is organized into modules (one .h/.cpp file per responsibility);
  this .ino contains only the high-level orchestration:

    Config.h          - pins and shared constants
    StatusLED         - RGB LED, recomputed on every loop() from the
                         current state (see StatusLED.h for the color table)
    BatteryMonitor     - reading/percentage of the 3.7V 360mAh LiPo
    PowerManager       - power switch + deep sleep (System OFF)
    MadgwickAHRS       - orientation filter (quaternion)
    MotionTracker      - IMU reading, world-frame rotation, velocity/
                         position integration, phase/rep identification (see MotionTracker.h)
    BleServer          - custom BLE service (streaming + commands), PERIPHERAL role

  Required library: "Seeed Arduino LSM6DS3" by Seeed Studio (the BLE
  library, Bluefruit52Lib, is already included in the Seeeduino:nrf52
  board package).

  Power switch: connect a switch between WAKE_PIN (D6, see Config.h) and
  GND. Switch closed = on; switch open = deep sleep, wakes with a full
  reset when closed again. BLE (Bluefruit.begin()) must be started BEFORE
  any possible call to goToSleep(): deep sleep uses
  sd_power_system_off(), which requires the SoftDevice to already be
  active.

  BLE flow (see BleServer.h for the exact packet layout):
  - SystemStatus can be read at any time with a standard GATT Read (in
    addition to the automatic push via Notify on every connection and on
    every state change).
  - Orientation calibration must be explicitly requested with the
    CALIBRATE (0x02) command when SystemStatus reports calibrated=false.
    START (0x01) is ignored if the system isn't calibrated yet; CALIBRATE
    is ignored if tracking is active (it must be stopped first with STOP,
    0x00).
  - While tracking is active: fast decimated streaming (body-frame and
    world-frame acceleration, RAW velocity and world-frame position on
    all 3 axes, quaternion - v3.11.0: Z velocity is never corrected in
    real time, see CorrectedCurve below) + a RepSummary packet (Notify,
    without a GATT ack - see BleServer::sendRepSummary()) on every valid
    completed rep (concentric plus any preceding eccentric phase, see
    RuntimeConfig::repDirection and MotionTracker.h/.cpp for the
    phase/bracket algorithm). v3.11.0: the SAME rep can be re-sent with
    an improved RepSummaryPacket::correctionStatus when the bracket
    containing it closes - the client overwrites by repNumber. In
    parallel, on every bracket close one or more CorrectedCurve (Notify)
    blocks arrive with the CORRECTED velocity for the time interval
    already transmitted via Stream as raw - see BleServer.h.
    Phases that are too short (likely bounce/noise) are discarded
    internally and never reported.
    Tracking continues even through a BLE disconnect/reconnect: it is
    never automatically stopped on the firmware side.
  - Config (Read/Write): algorithm parameters adjustable at runtime (rep
    direction Up/Down, anti-bounce, phase thresholds - see RuntimeConfig
    in MotionTracker.h) - consumed below with
    BleServer::takeConfigUpdate()/MotionTracker::setConfig(). NOT
    persisted to flash: every reboot starts again from the compiled
    defaults.
  - Every 30 seconds, independent of tracking: battery status (standard
    Battery Service, see BleServer.h).
*/

#include <Adafruit_TinyUSB.h>
#include <ctype.h>  // tolower() - see handleSerialCommandLine() below
#include "Config.h"
#include "StatusLED.h"
#include "BatteryMonitor.h"
#include "PowerManager.h"
#include "MotionTracker.h"
#include "BleServer.h"

unsigned long lastBatteryCheckTime = 0;
uint8_t streamDecimationCounter = 0;

// v3.11.21: minimal non-blocking line reader for START/STOP/CALIBRATE over
// serial - requested to drive tracking (and, v3.11.22, calibration) from
// tools/vbt_live_monitor.py (a desktop GUI with no BLE access), without
// adding a general command protocol. Config stays BLE-only (unchanged) -
// it already has a typed BLE packet (see BleServer.h) a text command
// would just duplicate. CALIBRATE (v3.11.22) is still exactly as blocking
// and pose-sensitive here as it is over BLE (~2s, device must be held
// still - see MotionTracker::calibrateOrientation()) - this only adds a
// second way to TRIGGER it, not a safer one; the same care applies
// whichever source sends it. Reads Serial.available() char-by-char
// instead of Serial.readStringUntil()/parseInt() (which block up to
// Serial's timeout, default 1s, when a line is incomplete) so a stray or
// partial command can never stall the 100Hz sampling loop.
char serialCmdBuf[16];
uint8_t serialCmdLen = 0;

bool serialCmdEqualsIgnoreCase(const char* a, const char* b) {
  while (*a && *b) {
    if (tolower((unsigned char)*a) != tolower((unsigned char)*b)) return false;
    a++; b++;
  }
  return *a == *b;
}

void handleSerialCommandLine(const char* line) {
  if (serialCmdEqualsIgnoreCase(line, "START")) {
    if (!MotionTracker::isCalibrated()) {
      Serial.println("START (serial) ignored: calibrate the device first (CALIBRATE command).");
    } else {
      MotionTracker::setTrackingActive(true);
      BleServer::updateSystemStatus(true, true);
      Serial.println("START (serial): tracking active.");
    }
  } else if (serialCmdEqualsIgnoreCase(line, "STOP")) {
    MotionTracker::setTrackingActive(false);
    BleServer::updateSystemStatus(MotionTracker::isCalibrated(), false);
    Serial.println("STOP (serial): tracking stopped.");
  } else if (serialCmdEqualsIgnoreCase(line, "CALIBRATE")) {
    if (MotionTracker::isTrackingActive()) {
      Serial.println("CALIBRATE (serial) ignored: stop tracking (STOP) before recalibrating.");
    } else {
      MotionTracker::calibrateOrientation();
      BleServer::updateSystemStatus(true, false);
      Serial.println("CALIBRATE (serial): calibration complete.");
    }
  } else if (line[0] != '\0') {
    Serial.print("Unknown serial command: ");
    Serial.println(line);
  }
}

// v3.11.23: user-reported - the status LED (see StatusLED.h) kept blinking
// red ("not connected") while driving the device entirely from
// tools/vbt_live_monitor.py over serial, because it only ever looked at
// BleServer::connected() - true "not connected" state for a workflow that
// was never going to use BLE at all in that session. `Serial` (the native
// USB CDC connection - Adafruit_USBD_CDC, see the `while (!Serial...)`
// wait already used at the top of setup()) is truthy exactly when a host
// has the port open (DTR asserted), the same signal a serial tool like
// vbt_live_monitor.py provides just by being connected - no explicit
// "hello" needed. deviceConnected() below is the single place that
// combines the two: BLE and USB-serial are two independent, simultaneous
// transports (nothing here disables one when the other is active), but
// for the LED's purposes either one being present means the device isn't
// sitting unconnected.
bool deviceConnected() {
  return BleServer::connected() || (bool)Serial;
}

void pollSerialCommands() {
  while (Serial.available() > 0) {
    char c = (char)Serial.read();
    if (c == '\n' || c == '\r') {
      if (serialCmdLen > 0) {
        serialCmdBuf[serialCmdLen] = '\0';
        handleSerialCommandLine(serialCmdBuf);
        serialCmdLen = 0;
      }
    } else if (serialCmdLen < sizeof(serialCmdBuf) - 1) {
      serialCmdBuf[serialCmdLen++] = c;
    }
    // else: overlong garbage line - silently dropped, buffer stays bounded
  }
}

void setup() {
  PowerManager::begin();
  StatusLED::begin();
  BatteryMonitor::begin();

  Serial.begin(115200);
  while (!Serial && millis() < 3000) { }

  // TEMPORARY DIAGNOSTICS to isolate the wake-from-sleep issue: remove
  // once resolved. The DOG case would confirm (or, if it never appears
  // again, rule out) the hypothesis of a firmware hang saved by the
  // watchdog that was just added (see PowerManager.h).
  Serial.print("RESETREAS = 0x");
  Serial.print(PowerManager::lastResetReason(), HEX);
  if (PowerManager::lastResetReason() & POWER_RESETREAS_OFF_Msk) {
    Serial.println(" -> wake from System OFF via GPIO (SENSE/DETECT) OK");
  } else if (PowerManager::lastResetReason() & POWER_RESETREAS_DOG_Msk) {
    Serial.println(" -> WATCHDOG RESET: the firmware was stuck (hang/crash) and self-recovered");
  } else if (PowerManager::lastResetReason() & POWER_RESETREAS_LOCKUP_Msk) {
    Serial.println(" -> CPU LOCKUP RESET: unhandled hard fault");
  } else if (PowerManager::lastResetReason() == 0) {
    Serial.println(" -> true POWER-ON RESET (power reconnected from scratch, not a wake from sleep)");
  } else {
    Serial.println(" -> other reason (see the comment in PowerManager.cpp for the bit meanings)");
  }

  // BLE must be started BEFORE any possible goToSleep():
  // sd_power_system_off() requires the SoftDevice to already be active
  // to work reliably.
  BleServer::begin();
  BleServer::updateSystemStatus(false, false);

  // v3.11.6: take the first battery reading IMMEDIATELY, without waiting
  // for the first periodic cycle (Config::BATTERY_CHECK_INTERVAL_MS,
  // 30s) - without this, the Battery Level characteristic (BLEBas) stays
  // at whatever default value the SoftDevice assigns it when it's
  // registered (BLEBas::begin() never writes an initial value, see
  // Bluefruit52Lib/src/services/BLEBas.cpp) until the first real
  // sendBattery() - if a client connects and reads it within that 30s
  // window (typical right after power-on), it reads nonsensical
  // percentages (any value 0-255, so both "0%" and "over 200%" are
  // possible) instead of an explicit error. Reported by the user: "as
  // soon as I connect the device the battery shows absurd values".
  BleServer::sendBattery(BatteryMonitor::voltageToPercent(BatteryMonitor::readVoltage()));

  // If the switch is NOT closed right at startup, go back to sleep immediately
  if (!PowerManager::wakeSwitchClosed()) {
    PowerManager::goToSleep();
  }

  if (!MotionTracker::begin()) {
    Serial.println("ERROR: IMU not initialized.");
    while (1) {
      // The LED keeps reflecting connection/state even in error
      // (blinks yellow if not connected, solid yellow if connected).
      StatusLED::update(deviceConnected(), false, false);
      delay(100);
    }
  }

  lastBatteryCheckTime = millis();
}

void loop() {
  // Feed the watchdog (see PowerManager.h): must be called on every
  // iteration, first thing, so that ANY block further down in the loop
  // (including one inside goToSleep() itself, if the switch is open)
  // remains uncovered and leads to the automatic reset within the
  // timeout.
  PowerManager::feedWatchdog();

  // Switch open -> go back to sleep
  if (!PowerManager::wakeSwitchClosed()) {
    PowerManager::goToSleep();
  }

  // --- LED: recomputed every cycle from the current state (see StatusLED.h) ---
  StatusLED::update(deviceConnected(), MotionTracker::isCalibrated(), MotionTracker::isTrackingActive());

  // --- Commands received via BLE ---
  if (BleServer::takeCalibrateRequested()) {
    if (MotionTracker::isTrackingActive()) {
      Serial.println("CALIBRATE ignored: stop tracking (STOP) before recalibrating.");
    } else {
      MotionTracker::calibrateOrientation();
      BleServer::updateSystemStatus(true, false);
      Serial.println("Calibration complete.");
    }
  }
  if (BleServer::takeStartRequested()) {
    if (!MotionTracker::isCalibrated()) {
      Serial.println("START ignored: calibrate the device first (CALIBRATE command).");
    } else {
      MotionTracker::setTrackingActive(true);
      BleServer::updateSystemStatus(true, true);
    }
  }
  if (BleServer::takeStopRequested()) {
    MotionTracker::setTrackingActive(false);
    BleServer::updateSystemStatus(MotionTracker::isCalibrated(), false);
  }

  // --- Commands received via Serial (START/STOP/CALIBRATE - see the
  // version note on pollSerialCommands() above) ---
  pollSerialCommands();

  RuntimeConfig newConfig;
  if (BleServer::takeConfigUpdate(newConfig)) {
    MotionTracker::setConfig(newConfig);
    Serial.println("MotionTracker: new configuration applied via BLE.");
  }

  // --- Battery status, every 30 seconds (independent of tracking) ---
  unsigned long now = millis();
  if (now - lastBatteryCheckTime >= Config::BATTERY_CHECK_INTERVAL_MS) {
    lastBatteryCheckTime = now;
    float vbat = BatteryMonitor::readVoltage();
    float pct = BatteryMonitor::voltageToPercent(vbat);
    Serial.print("Battery: ");
    Serial.print(vbat, 2);
    Serial.print(" V (");
    Serial.print(pct, 0);
    Serial.print("%)");
    Serial.println(BatteryMonitor::isCharging() ? " [charging]" : "");
    BleServer::sendBattery(pct);
  }

  // --- Orientation/motion: always updated (100Hz internal) ---
  // update() self-limits to 100Hz and returns true ONLY when it has
  // computed a real sample: anything that must happen "once per sample"
  // (BLE streaming decimation) must be gated on this, otherwise loop()
  // (which runs much faster than 100Hz) would repeat the same stale
  // sample multiple times between one real update and the next.
  bool newSample = MotionTracker::update();

  if (newSample && MotionTracker::isTrackingActive()) {
    // End-of-rep data BEFORE streaming. v3.10.3: peekCompletedRep() does
    // NOT remove the rep from the queue - it's removed with
    // popCompletedRep() ONLY if sendRepSummary() returns true (notify
    // sent successfully). If it fails (BLE not yet ready to notify, or
    // momentarily disconnected), the rep stays in the queue and is
    // retried on the next sample - NEVER lost. Before this version,
    // indicate() was used (blocking GATT confirmation, WITHOUT a timeout
    // - see the RepSummary comment in BleServer.h), which in the worst
    // case blocked the entire loop() (and therefore also IMU sampling)
    // waiting for the client, the diagnosed cause of missing/delayed
    // reps reported by the user.
    RepResult rep;
    if (MotionTracker::peekCompletedRep(rep)) {
      if (BleServer::sendRepSummary(rep)) {
        MotionTracker::popCompletedRep();
      }
    }

    // Corrected curve blocks (v3.11.0, see CorrectedCurve in
    // BleServer.h) - same peek/pop scheme as RepSummary above: a block
    // stays in the queue until notify() is sent successfully, so no
    // piece of corrected curve is ever lost.
    CorrectedCurveChunk chunk;
    if (MotionTracker::peekCorrectedCurveChunk(chunk)) {
      if (BleServer::sendCorrectedCurveChunk(chunk)) {
        MotionTracker::popCorrectedCurveChunk();
      }
    }

    // Fast streaming, decimated relative to the internal 100Hz - disabled
    // while a USB-serial connection is open (v3.11.24: automatic, was
    // gated on the manually-set RuntimeConfig::debugLogEnabled before -
    // see the version note in MotionTracker.cpp and serialLogActive()
    // there): the raw serial log that takes over in that case is already
    // at 100Hz (5x denser than this 20Hz stream), so sending both would
    // be redundant, and this notify() would compete for the same loop()
    // cycle right when we're trying to get the cleanest possible capture.
    streamDecimationCounter++;
    if (streamDecimationCounter >= Config::STREAM_DECIMATION_FACTOR) {
      streamDecimationCounter = 0;
      if (!(bool)Serial) {
        BleServer::sendStream(MotionTracker::currentSample());
      }
    }
  }
}

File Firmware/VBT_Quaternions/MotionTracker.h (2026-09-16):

// Part of the ODKI VBT Firmware
// Copyright (C) 2026 Lodovico Cortelazzo
//
// Licensed under the GNU General Public License, Version 3 (this
// specific version only, not "or any later version"), modified by the
// Commons Clause License Condition v1.0 -- see LICENSE-FIRMWARE in the
// repository root for the full text of both. In short: you may use,
// study, modify, and share this file (including a modified version) for
// non-commercial purposes; you may not sell it, or a product/service
// substantially derived from it, without a separate agreement with the
// copyright holder.
//
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
#ifndef MOTION_TRACKER_H
#define MOTION_TRACKER_H

#include <Arduino.h>

// v3.11.0: tracking engine replaced in its entirety (see the version note
// at the top of MotionTracker.cpp for the full diagnosis that led to this
// change). The old segment/ZUPT engine (boundary = confirmed stillness,
// then retroactive search for zero-crossings) is replaced by a "phase"
// engine (opened/closed for flatness, reversal, or timeout - IDENTICAL to
// how it was in firmware V2.0) + a "bracket" drift-correction layer: the
// integrated velocity always stays RAW (never zeroed/leaked), phases are
// closed when a bracket (= interval between two moments of confirmed
// stillness) closes, the drift measured at that moment is applied
// RETROACTIVELY and linearly over time to all samples in the bracket.
// Validated against 8 real hardware logs (STACCHI_1/2, SQUAT_1-6) with a
// Python simulator (sim_v2_drift.py) before being ported here - see the
// comments in the .cpp for the detail of each mechanism.

// Instantaneous phase state of ONE sample - see MotionSample::phaseState.
// v3.11.3: computed from the SIGN of refVelZ (with a small dead band),
// NOT from the open/closed state of the phase/bracket engine (that is
// deliberately debounced - it requires reversalConfirmSamples consecutive
// samples before confirming a reversal, see
// RuntimeConfig::reversalConfirmSamples - and by construction it lags
// behind a zero-crossing visible on the graph: reported by the user, who
// saw the eccentric phase still colored blue for a stretch after the
// curve had already dropped below zero). It can therefore oscillate for
// a couple of samples right at the true reversal point - it is meant
// ONLY for the live graph (coloring eccentric/concentric while moving),
// it is NOT the source of truth for the peak/mean reported at the end of
// a rep (that remains the phase/bracket engine).
enum class PhaseState : uint8_t {
  Idle = 0,       // sensor confirmed still (see confirmedStillNow)
  Eccentric = 1,  // negative refVelZ - descending
  Concentric = 2, // positive refVelZ - ascending
};

// Motion sample updated on every cycle (100Hz). linAcc* = acceleration in
// the sensor frame (gravity removed). world* = the same quantities in the
// world frame (fixed axes). refVelZ is the LIVE directional velocity
// (v3.11.0: no longer continuously zeroed/leaked by a ZUPT) - see the
// CorrectedCurve comment in BleServer.h for how/when the RETROACTIVELY
// corrected version for the same time interval arrives.
// v3.11.2: refVelZ is velZ (the raw integrator, never touched) RELATIVE
// to the measurement anchor (baselineRawVel) - this anchor is kept
// continuously aligned to velZ for the entire time the engine confirms
// the sensor is still (the same robust condition - two dynamic windows +
// an absolute ceiling on the already-corrected estimate - that already
// decides when to close phases/brackets, see the end of
// stepPhaseEngine() in MotionTracker.cpp), so it reads ~0 continuously
// during a real pause (not just for an instant) instead of staying stuck
// on a not-yet-converged bias residual. During motion it shows the raw
// delta from the last confirmed still reference - not yet corrected for
// THIS rep's drift (that's only known once the bracket closes, see
// CorrectedCurve). This is not a return to v3.10.x's ZUPT: velZ itself is
// NEVER zeroed, only the anchor used to reference this value - the
// bracket correction math (drift = velZ - baseline) remains identical.
// worldPosZ is a live integration of the same quantity (so with the same
// behavior), for the graph only - the authoritative data for each
// completed rep comes from peekCompletedRep().
struct MotionSample {
  float linAccX = 0, linAccY = 0, linAccZ = 0;
  float worldAccX = 0, worldAccY = 0, worldAccZ = 0;
  float worldVelX = 0, worldVelY = 0;
  float refVelZ = 0; // RAW live directional velocity, signed (see above)
  float worldPosX = 0, worldPosY = 0, worldPosZ = 0;
  float quatW = 1, quatX = 0, quatY = 0, quatZ = 0;
  PhaseState phaseState = PhaseState::Idle;
};

// Drift-correction status of a phase (eccentric or concentric) - see the
// version note at the top of MotionTracker.cpp. Increasing order of
// reliability: a phase reported as Provisional/RepCalibrated can be
// RE-reported (same repNumber, RepSummary again) as Corrected as soon as
// the bracket containing it actually closes.
enum class CorrectionStatus : uint8_t {
  Provisional = 0,   // corrected with the still-open bracket's EMA estimate
  RepCalibrated = 1, // corrected with the global calibration from rep cycles (no bracket available)
  Corrected = 2,      // corrected with a closed bracket's MEASURED drift - final
};

// Summary of ONE rep = a concentric phase + any eccentric phase preceding
// it in the same cycle (see RepDirection below for which direction is
// "concentric"). v3.11.0: a rep can be reported MULTIPLE TIMES with the
// same repNumber, as its phases move from Provisional/RepCalibrated to
// Corrected (see correctionStatus) - the receiver must overwrite by
// repNumber, not append.
// quality1: 0-100, kinematic coefficient (displacementM vs
// meanVelocity*duration, see the _score_phase equivalent in
// MotionTracker.cpp).
// correctionStatus: the worst (least reliable) of the eccentric phase's
// status and the concentric phase's status - see CorrectionStatus above.
struct RepResult {
  uint8_t repNumber = 0;
  float peakVelocity = 0;
  float meanVelocity = 0;
  float peakAcceleration = 0;
  float meanAcceleration = 0;
  float displacementM = 0;
  float eccPeakVelocity = 0;
  float eccMeanVelocity = 0;
  uint8_t quality1 = 0;
  CorrectionStatus correctionStatus = CorrectionStatus::Provisional;
};
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

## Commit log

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2026-09-16 Fix flat-guard reset delay, rep-numbering desync, velocity clamp target, and rep-calib refit discontinuity; add serial control + live monitor tool
    - v3.11.17: flat-guard window reset now uses MIN window size instead of
    MAX, fixing the slow (~1s) ZUPT reset after a genuine stop
    - v3.11.18: rep-number increment no longer depends on strict phase
    alternation, fixing permanent rep-numbering desync after a single
    same-direction phase split
    - v3.11.19: maxPlausibleVelocityMps clamp moved from velZ (raw, never-
    reset integrator) to velZLive, preventing corruption of the bracket
    drift measurement
    - v3.11.20: repCalibIntercept continuity patch after refitRepCalibration()
    removes a mid-phas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
    [MotionTracker.h, VBT_Quaternions.ino, vbt_live_monitor.py]
2026-09-16 v3.11.26: bound the EMA drift-rate estimate - cap its extrapolation and weight its update by bracket duration
    User-reported from a real capture (STACCO_2.log, a heavy/slow deadlift
    rep): velZLive started diverging from velZ about 5s into the session,
    reaching nearly double the raw value before snapping back once the rep
    reversed. Traced to two compounding issues in the EMA drift-rate path of
    livePredictedOffset()/closeBracketFn() (the branch active while
    repCalibCount < 2):
    - closeBracketFn() moved emaRate by the same emaAlpha regardless of how
    long the closing bracket ran, so a 150ms noise bracket could seed a
    rate as confidently as a full 1-2s one - in the capture, seeding 0.206
    m/s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
2026-09-16 v3.11.27: two-tier flat-guard, fixing a stuck correction offset after deadlift ground impact
    User-reported still unresolved on a second real deadlift capture
    (STACCO_3) even after v3.11.26 bounded the EMA drift-rate: the bar's
    ground contact is a real, expected deceleration, and velZ settles
    genuinely flat within under a second of it - but the existing safety net
    for this (flatGuardOverrideStillTimeS, a raw gyroscope/accelerometer
    1.0s-quiet override) never fired even once in the whole capture, because
    post-impact ringdown scatters small noise samples through that window,
    each one forcing the full second to restart from scratch.
    Considered and rejected (confirmed by simulating it against th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
    [MotionTracker.h]
2026-09-16 Cut firmware release v3.11.27; add matching companion app APK
    Replaces vbt_firmware_3.11.16_OTA.zip with vbt_firmware_3.11.27_OTA.zip
    (built via arduino-cli --export-binaries, Seeeduino:nrf52:xiaonRF52840Sense)
    and updates manifest.json's version/url/notes accordingly, per the
    5-step process in Firmware/firmware-release/README.md - this is what the
    companion app's FirmwareUpdateService fetches live from the default
    branch to offer the OTA (BLE Secure DFU) update.
    Notes call out the BLE protocol change explicitly (Config characteristic
    38 vs. the old 40/39 bytes - see the v3.11.27 commit) so testers know to
    update the app first, even though the update check/download itself
    still works agains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
2026-10-24 Companion app 1.0.3 APK
    Pairs with firmware 3.11.31: sends the Config packet in 20-byte chunks
    (fixes the disconnect a few seconds after connecting on some Android
    tablets) and skips the Config write on connect when the sensor already
    has the same settings. Also includes 1.0.2's fixes: location permission
    requested for BLE scanning on Android 7-11, and bundled fonts instead of
    fetching them at runtime.
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2026-11-01 Fusion feasibility study: build-time orientation filter switch and full-chain replay harness
    The CEO asked whether x-io Fusion (gyroscope offset correction, acceleration
    rejection) could replace the Madgwick filter. To answer it on real data:
    - Vendor Fusion v1.3.3 (commit 9325424, MIT, unmodified) under
    VBT_Quaternions/src/Fusion/ with its LICENSE.md and a VENDOR.txt note.
    - ODKI_ORIENTATION_FILTER in Config.h selects Madgwick (default) or Fusion at
    build time. FusionOrientation wraps Fusion behind MadgwickAHRS's interface,
    so MotionTracker's quaternion -> gravity split -> worldAccZ/worldAccZRaw path
    is unchanged. The Madgwick build is byte-identical to main (same .hex,
    arduino-c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
2026-11-01 fusion_feasibility: pre-3.11.30 config check, CALIBRATE convergence vs tilt, docs
    The Madgwick re-run reproduces the logged per-rep values to 0.0001 m/s once
    it uses the RuntimeConfig defaults the logs were recorded with
    (config=pre3.11.30), which separates engine-version differences from input
    reconstruction errors. Adds the time to recover from the mirrored CALIBRATE
    seed as a function of the sensor's tilt, for both filters.
2026-11-01 Session build 3.11.33-dev-session: fix the CALIBRATE seed, run-time filter switch
    Development build for the encoder recording session (CEO decisions of
    2026-11-01). Flashed over USB only: no manifest/OTA change, not a release.
    CALIBRATE seed. MadgwickAHRS::alignToGravity() built the rotation of the body
    Z axis onto the measured gravity, while update() and MotionTracker's gravBody
    read the quaternion the other way round: the seeded tilt was mirrored (off by
    2x the tilt; ~17 s to recover at rest at 72 deg, never at 90 deg). The seed is
    now built from gravBody(q) = a directly (minimal rotation, zero yaw, well
    conditioned from level to upside down). update() is untouched.
    tools/calibration_seed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
2026-11-02 Firmware 3.12.0: Fusion is the only orientation filter
    The x-io Fusion AHRS v1.3.3 (vendored unmodified in src/Fusion/, MIT,
    wrapped by FusionOrientation) replaces the Madgwick filter for good:
    MadgwickAHRS.h/.cpp, the build-time ODKI_ORIENTATION_FILTER switch, the
    run-time FILTER switch (ODKI_FILTER_RUNTIME_SELECT) and the dev build tag
    of the 3.11.33 session build are removed. Why: Fusion is maintained
    upstream under the MIT license, and the feasibility study (full-chain
    replay of 6 recorded squat sets, 55 reps) found Fusion - Madgwick per-rep
    mean velocity +0.004 +- 0.014 m/s, within what a 0.1% accelScaleG change
    does. Accuracy against an encoder is still to be validated.
    - CALIBRATE se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
2026-11-02 Bootloader guide (OTAFIX) and UF2 serial command
    The app's OTA update stalls with the bootloader the XIAO nRF52840 Sense
    ships with and completes with the community OTAFIX variant, so building
    or converting a sensor needs it. Hardware/Instructions/BOOTLOADER.md
    explains why, how to check the installed one (INFO_UF2.TXT, BLE name
    AdaDFU vs XIAO_DFU) and how to install it: method A with the reset
    button (UF2 drive), method B for a glued unit through USB only - B1 via
    the new UF2 command (keeps the firmware), B2 via adafruit-nrfutil serial
    DFU of the SoftDevice+bootloader zip with --touch 1200 (the bootloader
    Makefile's flash-dfu command; erases the firmware, which then goes back
    over BLE). Rec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
2026-11-03 Docs for 3.12.0: Fusion-only wording, known limitations, version status
    - DOCUMENTATION.md: drop references to the unreleased development
    build (serial commands, INFO/TIMING lines, log columns, CALIBRATE
    seed fix now dated v3.12.0); FILTER documented as read-only; Fusion
    chapter: feasibility result condensed, "Why these values" per
    setting (gain, acceleration rejection, rejection timeout, gyroscope
    range, bias/startup, normalisation wrapper); live monitor toolbar
    layout; new "Known limitations" chapter (about 95 Hz sampling,
    10-12 ms periods, true dt integrated, fix planned).
    - README.md: Status shows 3.12.0 as the version this branch prepares;
    bootloader step marked as neede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
2026-11-03 Remove the UF2 serial command from 3.12.0
    Tested on hardware (OTAFIX 0.9.2-OTAFIX2.3-BP1.4): the command printed its
    message and reset the board, but the XIAO-SENSE drive never appeared and
    the board booted straight back into the application. Rather than ship a
    command that does not work, 3.12.0 drops it; the 1200-baud touch (serial
    DFU) is unaffected.
    BOOTLOADER.md: method B1 (which relied on the command) is removed; closed
    units use the serial DFU method with --touch 1200 (formerly B2), with a
    note that a firmware command to open the drive was tried and does not
    work with OTAFIX 2.3. DOCUMENTATION.md: UF2 row and mention removed.
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2026-11-05 Firmware 3.12.1: CorrectedCurve no longer changes pauses
    While the sensor is confirmed still, the bracket anchor follows the
    current sample, but the still samples stayed in bracketBuf before t0.
    On the next bracket close enqueueCorrectedCurveChunks() extrapolated
    the drift ramp backwards over them, so a pause shown as 0 live became
    a non-zero velocity (up to 0.68 m/s on a recorded squat set). Now, with
    no phase open or pending, bracketBuf is cut back to the current sample.
    Replayed with tools/full_replay on 5 recorded squat sets: S/R/B/P output
    byte-identical to 3.12.0; every still sample in CorrectedCurve is 0.
    The full_replay harness can print the chunks (ODKI_DUMP_CHUNKS).
    Docs, BLE spec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
2026-11-06 Release 3.12.4 and companion app 1.0.6
    Firmware 3.12.4 (OTA live from this commit):
    - Accelerometer bias learns only after 0.3 s of stillness
    (accZBiasIdleStillTimeS 0.05 -> 0.3 s). With 0.05 s it also learned
    during slow, steady motion and absorbed real acceleration: live
    velocity drifted, stillness came late and one rep of ten was lost on
    a recorded deadlift set (10/10 with 3.12.4).
    - velZ (USB serial log) reads 0 during confirmed stillness: the velocity
    frame is shifted on every still sample; reps, corrected curve and
    live values are unchanged by this part.
    - Bias and drift-correction Config fields are firmware-only: values
    written over BLE are ignored and the compiled defau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
2026-11-07 Test build 3.12.6: landing impulse and orientation hold at shocks
    On a deadlift set with the bar put down on the floor 10 times, 3.12.4
    counted 4 reps with up to -12.8 m/s of drift in one bracket. Two causes:
    the aliased vibration of bar and plates makes the integrated landing
    impulse wrong-signed (-1.2..-2.0 m/s instead of about +0.5), and the
    same gyroscope burst rotates the quaternion until the tilt error reaches
    12-43 deg, past Fusion's 10 deg acceleration rejection, so the
    accelerometer is ignored and the attitude never recovers.
    A causal shock layer (60 ms of delay at most): a jerk detector on the
    unfiltered acceleration opens a shock window during which Fusion is not
    updated; a landi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
2026-11-07 Docs: align the 3.12.6 shock-layer description with the code
    - DOCUMENTATION.md, Mechanical shocks: candidate opens on any sample whose
    jerk exceeds the threshold with nothing in progress (also later in the same
    window); vPre is the unclamped live velocity before this sample's
    increment; the landing tests run on the clamped, directed worldAccZRaw and
    the gyro test is the maximum over the candidate; detector and landing state
    are reset at START/STOP and after CALIBRATE; a released candidate matches
    the trapezoidal integral (constant sample period).
    - S-row "shock" column: orientation held only while the window is open;
    state 3 makes velZLive read about 0 (exact unless the landin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
2026-11-07 Test build 3.12.7: re-level after a landing, still-bar shocks are landings
    A deadlift set recorded with 3.12.6 (8 reps, then the bar put down) gave
    7 reps, -1.20 m/s of drift in one bracket and -2.07 m/s of live velocity
    with the bar at rest at the end; no saturation. Two causes: the bar
    really rotates when it lands, and holding the orientation through the
    shock window throws that rotation away (the tilt error jumps by up to
    10 deg when the window closes and grows from pull to pull, 26-36 deg at
    the final put-down, past Fusion's acceleration rejection); and a second
    knock right after a landing came with vPre -0.02 m/s, above the -0.05
    the landing test required, so its vibration was integrate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
2026-11-07 Docs: align the re-level description with the code
    - DOCUMENTATION.md, re-level: samples with the orientation held are
    skipped (they neither count nor restart the still run, the timeout is
    only checked on samples that are not held); a later landing re-arms it;
    alignToGravity() also zeroes the FusionBias offset (off in the
    firmware, so no effect). Clarify "points 2 and 4" in the detector item.
    - FusionOrientation.h: alignToGravity() is no longer called only by
    CALIBRATE.
    - TrackingTypes.h: relevelEnabled = false alone does not give the
    previous engine; shockLandingMaxVPreMps = -0.05 is needed too.
    - MotionTracker.cpp: relevelStep() comment states the held-sample rule.
    Comments an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
2026-11-08 3.12.8: above-ceiling flat window accepts 10-40 samples, default 30
    The app is getting a wider range for velocityOverrideFlatWindowSamples
    (the fixed flatness window used once |velZLive| exceeds
    flatGuardMaxVelocityMps), so the firmware clamp in setConfig() moves from
    30..64 to 10..40. Replayed on 23 real logs, windows of 10-25 samples
    mistake the constant-velocity stretch of slow reps for stillness (squat
    sets change rep count, a slow deadlift rep drops from 0.47 to 0.20-0.22
    m/s), so the default stays 30 and the narrower windows are only for
    experiments. 40 only shifts per-bracket drift slightly.
    - MotionTracker.cpp: VELOCITY_OVERRIDE_WINDOW_MIN/MAX (10/40) used by the
    clamp; comments a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
2026-11-08 Diagnostic build 3.12.10: log the complete 416 Hz IMU stream from the FIFO
    The concentric-phase integration error on some deadlift reps (-0.2 to
    -0.3 m/s) may come from how the IMU is sampled: the engine integrates
    the mean of the readings poll() happens to catch, 2-3 per 10 ms in the
    3.12.7 log out of about 4.6. To compare the two offline on the same
    reps, this build also logs every 416 Hz reading. The engine is not
    touched: it still integrates the poll means.
    - FifoLogger (MotionTracker.cpp): LSM6DS3 FIFO in continuous mode,
    accel+gyro undecimated at 416 Hz. It is active only while recording
    with the USB log open, so BLE-only use does no extra I2C. All its work
    runs after a poll() t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
2026-11-08 Docs: align the H/HSTAT lines and fifo_worldz.py description with the code
    - DOCUMENTATION.md, fifo_worldz.py paragraph: rows without a matching
    run are not left out, they get their index from the fitted line and
    are counted as "fitted"; ambiguous rows take the run nearest the
    line. The comparison is with the poll mean recomputed from accRawX/Y/Z
    (the distance from the logged worldAccZRaw is printed too), phases are
    the reported P rows. Adds --session and what --csv writes.
    - H lines: not strictly one per sample (none when nothing new, one for
    two samples without an idle gap; the last one at REC_STOP between
    TIMING and HSTAT). Flag 8: a failed status read is retried, no gap.
    -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
2026-11-08 3.12.11 (test build): softer landing thresholds, FIFO log stall fix
    - shockLandingPeakAccMps2 25 -> 18, shockLandingSustainAccMps2 20 -> 15:
    three deadlift sessions gave 8/2/6 reps because soft landings
    (18-25 m/s^2 world Z) were not confirmed; replay gives 8/8/8, other
    recorded logs keep their rep counts.
    - FifoLogger: print the pending line after a gap without waiting for a
    status read (the stream stalled after the first misaligned read).
    - DOCUMENTATION.md: landing thresholds, shock section point 5, measured
    readings per mean at 100/400 kHz, H/HSTAT lines for both test builds.
2026-11-08 3.12.12 (test build): soft landings by 3D magnitude, FIFO log removed
    - Landing test: with vPre below shockLandingMagMaxVPreMps (-0.40 m/s)
    the peak/sustained tests also accept | |a| - accelScaleG | of the
    10 ms mean. Two 3.12.11 deadlift sessions 7 -> 8 reps in the replay,
    every other recorded log identical to 3.12.11.
    - FifoLogger removed: the 416 Hz data showed the lost readings cause
    neither the wrong landing impulse nor the concentric error.
    - DOCUMENTATION.md: shock section point 6, new config field, H/HSTAT
    lines limited to 3.12.10/3.12.11 (with the word-shift caveat).
2026-11-08 3.12.13 (test build): restart the drift regression at a landing
    A confirmed landing resets velZ, so the rep-cycle regression points and
    the zero-crossing interval spanning it no longer measure drift: restart
    the calibration (EMA until two new points) and drop the crossing
    reference. Replay: logs without landings identical; the 3.12.12 set's
    rep 2 1.16 -> 1.34 m/s, bracket drift 1.00 -> 0.06. DOCUMENTATION.md:
    shock section point 7.
2026-11-08 3.12.14 (test build): no stillness right after a suspended integration
    A held shock candidate or a landing window freezes velZ, which the
    flat-guard took for stillness (a bracket closed with the bar rising at
    +0.18 m/s at a lift-off). Stillness now needs stillSamplesAfterSuspend
    (3) normally integrated samples after a suspension;
    shockLandingMagMaxVPreMps -0.40 -> -0.30. Replay: two reps corrected
    (1.06 -> 1.27, 1.31 -> 1.45 m/s), every other log identical.
    DOCUMENTATION.md: shock section point 8, config table.
2026-11-10 3.12.15 (test build): no rep-cycle boundary at a dip at the top
    A dip of the bar at the top of a pull passed the -0.03 m/s excursion
    test, so the zero crossing after it split the rep into two half cycles
    whose net displacement (the whole range of motion) the drift regression
    read as +/-0.3 m/s of drift; in the 3.12.14 deadlift sets this moved
    velZLive by up to 1.9 m/s (p95) and merged or miscounted reps. A
    crossing is now a cycle boundary only if the live velocity also came
    down by minCrossingDescentM (0.05 m, not in the BLE packet) since the
    last one. Replay: deadlift sets 10 -> 11 and 9 -> 12 reps (12 pulls in
    the signal), a false put-down rep removed and a merged rep separated in
    another,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
2026-11-10 3.12.15 (test build): a confirmed landing closes the bracket
    The bracket correction spreads an error born in one instant over the
    whole bracket: in the 3.12.14 deadlift sets the error integrated right
    after the final put-down (attitude off after the impact, up to -2.65
    m/s of raw velocity) was spread back over the reps, turning the last
    rep's 0.82 m/s into 1.88. The bar is on the floor at a landing, so the
    landing now closes the bracket right after the landing impulse: the
    reps keep their own drift, the post-impact error goes to the next
    bracket, and the new anchor puts velZLive at 0. Replay: that rep 1.88
    -> 0.83 m/s (bracket drift -2.64 -> +0.01), same rep counts on every
    log, values withi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
2026-11-10 3.12.15 (test build): no integration of a wrong attitude after a landing
    After a hard put-down the attitude can stay far off until the re-level
    runs: on a 3.12.14 deadlift set worldAccZ read about -9 m/s^2 for 0.28 s
    with the bar on the floor and the raw velocity reached -2.65 m/s. After
    the landing window, while the re-level is armed, a sample whose median
    world-Z acceleration disagrees with the median |a| deviation by more
    than postLandingAccMismatchMps2 (4 m/s^2, not in the BLE packet) is now
    integrated as 0: for vertical motion the two agree whatever the
    attitude. Replay: that put-down -2.65 -> 0.00 m/s; elsewhere it fires on
    single samples, no value changes by more than 0.007. 2 m/s^2 c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
2026-11-10 3.12.16 (test build): worldPosZ is the signed live position of the rep
    worldPosZ (serial log column and BLE Stream field) integrated refVelZ
    only while it was positive and was cut to 0 at every reversal: it showed
    the rising part of a rep only, never the descent and never back to 0 at
    its end. It is now the position-gate position: integrated from velZLive
    since the last confirmed stillness or landing, signed in the rep frame,
    0 while still. Same Stream layout and scale (int16 /1000 m, signed); the
    meaning of the field changes, so BLE_PROTOCOL.md describes it. Live,
    not retroactively corrected; RepSummary.displacementM is unchanged.
    Replay: reps and values identical to the previous commit.
    DO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
2026-11-10 3.12.16 (test build): log the active Config at every REC_START
    A recorded squat set had run with two flat windows the app had changed
    over BLE, and nothing in the log showed it: the replay could only infer
    it. The firmware now prints a CONFIG line (the BLE-writable RuntimeConfig
    fields, key=value) after INFO at every REC_START and whenever a new
    configuration is applied. full_replay applies the block's first CONFIG
    line (--set cfg.<field> overrides it), vbt_log_viewer reads it with the
    session info. Log-only, no BLE change. A replayed log replayed again
    with its own CONFIG line: velZ identical, same B and P rows. A block with
    an INFO line is no longer taken for a joined session.
    DOCUMENTATIO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
2026-11-10 3.12.17 (test build): worldPosZ reset per rep cycle, residual logged
    worldPosZ (log column and BLE Stream field) was reset at every
    stillness, so it never showed whether the bar came back to where a rep
    started. It now integrates velZLive through pauses and is reset only
    when a rep cycle is complete: the first reported phase of the session
    sets the starting type (eccentric for a squat, concentric for a
    deadlift from the floor), the next reported phase of the other type
    ends the cycle. The position at that phase's last kept sample is the
    cycle's integration error: printed as a new Y row and subtracted. The
    position gate keeps its own position, so reps and values are identical
    to 3.12.16 on ev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
2026-11-11 Release 3.12.17 and companion app 1.0.7
    Firmware 3.12.17 (OTA live from this commit), includes 3.12.5-3.12.16:
    - Barbell landings: the impact impulse is replaced, a confirmed landing
    closes the drift bracket, no integration of an inconsistent attitude
    after a landing, re-level after the landing.
    - Rep-calibration crossings need a real descent (no half cycles from a dip
    at the top); EMA drift-rate seed limited.
    - Stillness gate: no stillness mid-range while moving (squat sticking
    point) or during a constant-speed descent.
    - worldPosZ (serial log and BLE Stream): signed live position, reset at
    the end of each rep cycle; BLE layout unchanged.
    - Serial log: CONFIG row at every REC_STAR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
2026-11-12 Companion app 1.0.8: OTA recovery for a sensor left in update mode
    - Android APK replaced with 1.0.8 (versionCode 11), same signing key.
    - Apps/Android/README.md: keep the app on screen during an update; Retry,
    FINISH UPDATE on 'Sensor in update mode', settings fallback.
    - BOOTLOADER.md: recovery after an interrupted OTA from the app.
2026-11-12 Simple, safe software install: bootloader over USB (no reset button), firmware from the app
    - BOOTLOADER.md rewritten as one tested path for bare boards and closed
    units: check the file, 1200-baud reset, adafruit-nrfutil, FINISH UPDATE
    in the app, D6 switch note; UF2 drive kept as the alternative.
    - Assembly guide: switch first, software over USB with no battery, battery
    last with USB unplugged and switch off.
    - README Getting started and Hardware/README point to the guide; Arduino
    IDE only for changing the firmware.
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

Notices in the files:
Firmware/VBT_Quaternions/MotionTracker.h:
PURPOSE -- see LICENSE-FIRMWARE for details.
